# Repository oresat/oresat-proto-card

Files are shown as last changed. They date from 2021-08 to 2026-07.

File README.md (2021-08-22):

# "oresat-proto-card"

This is the "prototype" card for OreSat, meant to pioneer future cards and test the backplane, and be an 
easy way to hack in functionality. NOT MEANT FOR FLIGHT.

## Features

- Populates the two 1.27 mm connectors from the backplane.
- Populates all three SMPM RF connectors from the backplane.
- Standard TPS63070-bsaed buck/boost SPS (Vin = 2.5 to 7 V, Vout = 3.3V)
- Has our standard/favorite STM32F042K6 microcontroller.
   - With SWD, UART (FTDI), and CAN (to the backplane).
- Has lots of breakouts, but DO NOT POPULATE THE 0.1 IN CONNECTORS, THEY'RE TOO TALL!!!

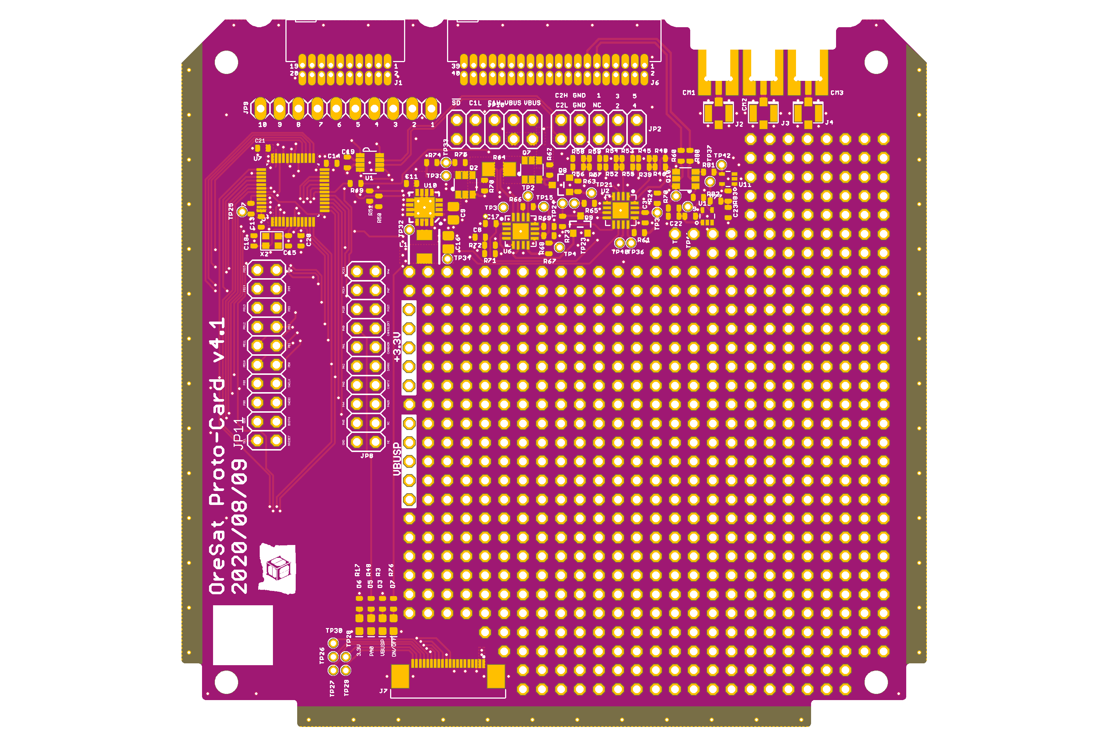
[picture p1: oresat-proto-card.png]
OreSat ProtoCard Picture


## Connector information

- Main 1.27 mm connector ("Center" connector)
   - Samtec TFM-120-01-L-D-RA
   - https://www.digikey.com/products/en?lang=en&site=US&keywords=TFM-120-01-L-D-RA
   - Drawing: http://suddendocs.samtec.com/prints/tfm-1xx-xx-xxx-d-xxx-mkt.pdf
   - Brochure: http://suddendocs.samtec.com/catalog_english/tfm.pdf
   - 3D CAD: https://www.samtec.com/partnumber/tfm-120-01-l-d-ra?vendor=digikey#technical
   - Notes: the -RE1 model is better because of the solder stakes, but the female connector doesn't fit! The stakes get in the way :(

- Auxiliary 1.27 mm ("alt-left" connector)
   - Samtec TFM-110-01-L-D-RA

- RF (70 cm, L band, S band) conenctors
   - Card
      - Molex 73300-0030 (possible replacement is 73300-0020 but it has full detent that we don't want)
      - SMPM Connector Plug, Male Pin 50 Ohm Board Edge, Cutout; Surface Mount Solder, smooth bore
      - Molex w/3D: https://www.molex.com/molex/products/datasheet.jsp?part=active/0733000030_RF_COAX_CONNECTORS.xml
   - Barrell (connects card to backplane)
      - Molex 73300-0220 (alt but slightly different lengths: -0223, -0228)
      - SMPM female to female barrel adapter 
      - RF Adapters - In Series SMPM JACK/JACK BULLET .21IN
      - Molex w/3D: https://www.molex.com/molex/products/datasheet.jsp?part=active/0733000220_RF_COAX_CONNECTORS.xml

## OreSat Power Domain (OPD)

You can find more design information on the OPD [here](https://docs.google.com/document/d/1NOkO6gGEJUFRpOrkwClRlZlzWuTLteq6fP9LPf_Ez0M/edit?usp=sharing).

## LICENSE

Copyright Portland State Aerospace Society 2018.

This documentation describes Open Hardware and is licensed under the CERN OHL v. 1.2.

You may redistribute and modify this documentation under the terms of the CERN OHL v.1.2. [http://ohwr.org/cernohl](http://ohwr.org/cernohl). This documentation is distributed WITHOUT ANY EXPRESS OR IMPLIED WARRANTY, INCLUDING OF MERCHANTABILITY, SATISFACTORY QUALITY AND FITNESS FOR A PARTICULAR PURPOSE. Please see the CERN OHL v.1.2 for applicable conditions.

## Version Information

Version | Date       | Notes
--------|------------|-------------------------
3.0     | 2018/11/22 | Big changes in structure, mostly springs. Changed RF connectors to SMPM. Optimized layout for more proto area. 
2.0     | 2018/03/?? | New 1.27 mm connectors, again.
1.0     | ??         | New connectors.

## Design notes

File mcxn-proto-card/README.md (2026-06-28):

---
title: "**OreSat MCXN Proto Card**"
subtitle: |
  **Fabrication and Assembly Information**\
  For build TIME-STAMP
fontsize: 10pt
geometry:
  - margin=0.5in
toc: true
toc-depth: 2
colorlinks: true
urlcolor: blue
---

\newpage

# About this Board

## Board Description

The OreSat MCXN Proto Card is a generic OreSat card based on the NXP MCXN947 microcontroller. It has an OreSat Power Domain (OPD), 
a CAN interface, an OreSat Card Debug port, a bzillion test points, and a 0.1 inch hole prototyping area.

The proto card also has the OreSat auxiliary connector and 3 RF backplane connectors, but these are not placed since they're not usually used.

## Documentation Links

- Git repository: <https://github.com/oresat/oresat-flatsat>
- **TODO:** Design Notes + Design Review Notes

## Documentation Files

| Filename | Notes |
| --- | --- |
| README.pdf | This README file |
| PROJECT-NAME-outline.dxf | Board outline (with holes) in DXF format |
| PROJECT-NAME-pcba.step | 3D model of PCBA (with components) |
| PROJECT-NAME-render-bot.jpg | Render of the top of the 3D model |
| PROJECT-NAME-render-bot.jpg | Render of the bottom of the 3D model |
| PROJECT-NAME-schematic.pdf | PDF of board schematics |

## Contact Information

- Website: <https://www.oresat.org/>
- Email: <oresat@pdx.edu>
- Instagram: @pdxaerospace

## Board Renders

Render of the top of the 3D model
Render of the bottom of the 3D model

\newpage

# Printed Circuit Board (PCB) Fabrication Information

## Board Info

- 4 layer board
- Bounding box is 99.8 x 94.6 mm
- Board thickness is 1.59 mm

## Board Requirements

- Design Rules
    - Minimum Trace / Space design rules
       - Outer layers: 0.127 mm (5.0 mil) / 0.127 mm (5.0 mil)
       - Inner layers: 0.127 mm (5.0 mil) / 0.127 mm (5.0 mil)
    - Outer dimension router tolerance: +/- 0.254 mm (10.0 mil)
    - Hole placement tolerance: +/- 0.075 mm (3.0 mil)
    - Inner tab routed slot tolerance: +/- 0.254 mm (10.0 mil)
- Drills
   - Drill Positional Tolerance: 0.051 mm (2.0 mil)
   - Drill Size tolerance: +/- 0.064 mm (2.5 mil)
- Plated/Un-plated holes
  - Via/PTH minimum diameter: 0.254 mm (10 mil)
  - Via/PTH minimum annulus: 0.102 mm (4 mil) radius
- Outline/Routing
  - This board requires a 1 mm router bit.
- Slots
  - There are no slots.
- Cutouts
  - There are no cutouts
- There are 3 fiducials on the top layer.
- Panel tabs ("mouse bites")
   - Card edges must be smooth; no mouse bites or other intrusions into the card outline.
   - If external mouse bites are required, minimize and customer will remove by hand before assembly.
- If not otherwise specified, build to IPC 6012 Class 2 or better.

## Stackup /  Materials

- Outside copper layers is 1 oz Cu after plating (0.043 mm / 1.7 mil)
- Inside copper layers are 0.5 oz Cu (0.018 mm / 0.7 mil)
- There are no requirements on the prepreg or core of this four layer stackup.
- Board Surface treatment should be ENIG, althogh immersion Silver is acceptable.
- White silkscreen on top and bottom surface
- Taiyo PSR-4000 or equivalent soldermask on top and bottom, no requirements for color.

## Array / Panel Information

- Coordinate with Contract Manufacturer (CM) for optimal size of this panel.
- If no feedback from CM, then produce single boards (no panel).

## Fabrication Files

### IPC-2581 File

| Filename | Notes |
| --- | --- |
| PROJECT-NAME-ipc2581.xml | IPC-2581 board information file |

### Legacy PCB Files

| Filename | Notes |
| ---| --- |
| PROJECT-NAME-Edge_Cuts.gbr | RS274X file for the dimension (outline) layer |
| PROJECT-NAME-F_Silkscreen.gbr | RS274X file for the top silkscreen |
| PROJECT-NAME-F_Mask.gbr | RS274X file for the top soldermask |
| PROJECT-NAME-F_Cu.gbr | RS274X file for the top copper layer |
| PROJECT-NAME-In1_Cu.gbr | RS274X file for the layer 2 copper |
| PROJECT-NAME-In2_Cu.gbr | RS274X file for the layer 3 copper |
| PROJECT-NAME-B_Cu.gbr | RS274X file for the bottom copper layer |
| PROJECT-NAME-B_Mask.gbr | RS274X file for the bottom soldermask |
| PROJECT-NAME-B_Silkscreen.gbr | RS274X file for the bottom silkscreen |
| PROJECT-NAME-NPTH.drl | Excellon file for non-plated through holes |
| PROJECT-NAME-PTH.drl | Excellon file for plated through holes | 

\newpage

# Printed Circuit Board Assembly (PCBA) Information

## Assembly Info

- All components are on the top side of the board.
- This PCBA uses both surface mount (SMT) and through-hole (THT) components.

## Assembly Requirements

- Assemble to IPC Class 2 or better
- Bake components that are not moisture sealed to appropriate levels as required.
- Any solder paste (leaded or RoHS) is acceptable. RoHS solder is slightly preferred.
- Any no-clean or aqueous wash flux is acceptable.
- No conformal coating.

## Component Specific Assembly Information

- No specific information

## Assembly Files

### IPC-2581 File

| Filename | Notes |
| --- | --- |
| PROJECT-NAME-ipc2581.xml | IPC-2581 board information file |

### Bill of Materials (BOM)

| Filename | Description |
| --- | --- |
| PROJECT-NAME-bom.csv | BOM in Comma Separated Variable format |

### Solder Paste Stencils

| Filename | Notes |
| --- | --- |
| PROJECT-NAME-B_Paste.gbr | RS274X file for top/front solder paste stencil |
| PROJECT-NAME-F_Paste.gbr | RS274X file for bottom/back solder paste stencil |

### Mounting/Placement Location

| Filename | Description |
| --- | --- |
| PROJECT-NAME.pos | Pick and place locations for components |

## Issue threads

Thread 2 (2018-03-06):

Getting feedback on the v1.1 prototype card

andrewgreenberg, 2018-03-06:
Rough draft of the v2 card is done! We're now awaiting feedback that we're not complete idiots on the v1.1. We need to know:

1. Does it power up?
1. Can you program the STM?
1. Can you blink the LED?
1. Can you talk over UART?
1. Can you talk over CAN?

At that point, we can fire on v2!

heliochronix, 2018-03-09:
Feedback so far:
CAN_EN (PA10) and CAN_LSTN (PA9) are mislabeled, similar to the Solar V1 issue. They are connected to SHDN (Shutdown mode) and S (Silent mode) on the TCAN330.  Maybe rename CAN_SHDN and CAN_SILENT?

1. Powers up: Check
2. Programmable: Check
3. LED Blinks: Working on it. Some kinda hitch right now.
4. UART: Need to test
5. CAN: Need to test

andrewgreenberg, 2018-03-09:
Fixed in future OreSat Proto Card and on solar v2 boards. Now called CAN_SHDN and CAN_SILENT, as suggested. Go Miles go!

heliochronix, 2018-03-09:
1. Does it power up? Yes!
2. Can you program the STM? Yes!
3. Can you blink the LED? Yes!
4. Can you talk over UART? Yes!
5. Can you talk over CAN? Yes!

Closed 2018-03-09.

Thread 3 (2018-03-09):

FTDI Header has TX/RX swapped

heliochronix, 2018-03-09:
USART2_RX should connect to pin 4 (RXI)
USART2_TX should connect to pin 5 (TXO).

andrewgreenberg, 2018-03-12:
Fixed!

Closed 2018-03-12.

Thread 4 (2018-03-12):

Request power via FTDI Vcc

heliochronix, 2018-03-12:
Request a jumper or something be added to allow an FTDI cable's Vcc to supply power to the board. This will ease the requirement of needing an additional power supply when developing.

andrewgreenberg, 2018-03-12:
Added 1x2 0.1" jumper to go from FTDI VCC to VBUS.

Closed 2018-03-12.

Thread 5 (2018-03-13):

Power LED labelled VBAT instead of VBUS

heliochronix, 2018-03-13:
Simple as that. The LED for power is labelled VBAT and I noticed everything else is labelled VBUS now.

andrewgreenberg, 2018-03-13:
Fixed and pushed!

Closed 2018-03-13.

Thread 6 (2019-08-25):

OPD breaker trips with inrush current.

davidalay, 2019-08-25:
the OPD breaker trips from the inrush current when the board is powered on.  Can be reset, stuffing the reset circuitry should fix the problem

Closed 2020-06-22.

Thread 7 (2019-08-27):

IO0 on MAX7310 is open drain

davidalay, 2019-08-27:
IO0 on the IO expander is only open drain, needs to be switched with one of the other pins that can work with open drain (I2C?).   Cutting the trace and soldering a jumper from tp13 to tp10 to tie to the indicator LED should work as a temp fix.

Closed 2019-09-11.

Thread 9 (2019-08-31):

10-pin JTAG header is flipped/mirrored

heliochronix, 2019-08-31:
The JTAG header on these boards is opposite of what it should be. That is, 3.3V is on the "top left" in Eagle but it should be the "top right" and likewise for the "bottom left" and "bottom right". All the pins are mirrored "left-to-right".

davidalay, 2019-12-07:
Part fixed in the oresat eagle libraries

Closed 2019-12-07.

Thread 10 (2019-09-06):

I2C protection

davidalay, 2019-09-06:
Weird gate capacitance stuff happens with the I2C protection circuit.  New design coming in future revs to fix issue.  For now DNP the I2C MOSFETS and short the lines together.

davidalay, 2019-11-05:
Fixed in most recent push

davidalay, 2019-11-05:
Fixed in most recent push

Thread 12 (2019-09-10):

MAX4211 dies if VBUSP is shorted

davidalay, 2019-09-10:
The MAX4211 circuit breaker dies if VBUSP is shorted.  We are pretty sure its because the MCP1703 is dying.  Perhaps a diode and cap to fix?

Closed 2020-06-22.

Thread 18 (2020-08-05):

Oresat Debug Connector: Add TCREAM back on ground pads of thin debug connector

andrewgreenberg, 2020-08-05:

andrewgreenberg, 2020-08-09:
Won't fix; abandoning this connector because it's complete garbage.

Closed 2020-08-09.

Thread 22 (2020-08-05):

Remove STM32F04 from BOM and replace with STM32F09

davidalay, 2020-08-05:

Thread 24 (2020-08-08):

Protocard: Ciss (input capacitance) from P CH in OPD protection circuitry kills I2C rise times

andrewgreenberg, 2020-08-08:
The 300 pF input capacitance of the DMP2240UDM-7 dual P channel MOSFET (Q10)  we use in the I2C protection circuit (before the MAX7310) was killing the I2C signal. Removing the MIC comparitor, and just having the 10K to ground on the Q10 gates was too much. Raising that resistor to > 100k seems to solve the problem "enough".

So: change R77 and R81 to 665K (we already have that value) and move them between the MIC output and transistor. We'll have to no longer have the gate be pulled low, which seems OK? If we really want one, a 1 M to ground is probably OK but it'll affect the gate drive of the MIC so that'll have to be explored.

andrewgreenberg, 2020-08-09:
Fixed in DBLs; still needs to fix in protocard.

andrewgreenberg, 2020-08-10:
Fixed in protocard, now just need to hack existing v4.0 protoboards into compliance

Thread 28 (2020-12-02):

Implement inhibit RC filter on MAX4311 CB IC

andrewgreenberg, 2020-12-02:
See design.md in the protocard repo: C = 1 uF (Vw >= 16V), R = 100k, and then a 10k into the MAX4311 to protect it.

andrewgreenberg, 2020-12-02:
This is for DBL, protocard, and everything with an OPD.

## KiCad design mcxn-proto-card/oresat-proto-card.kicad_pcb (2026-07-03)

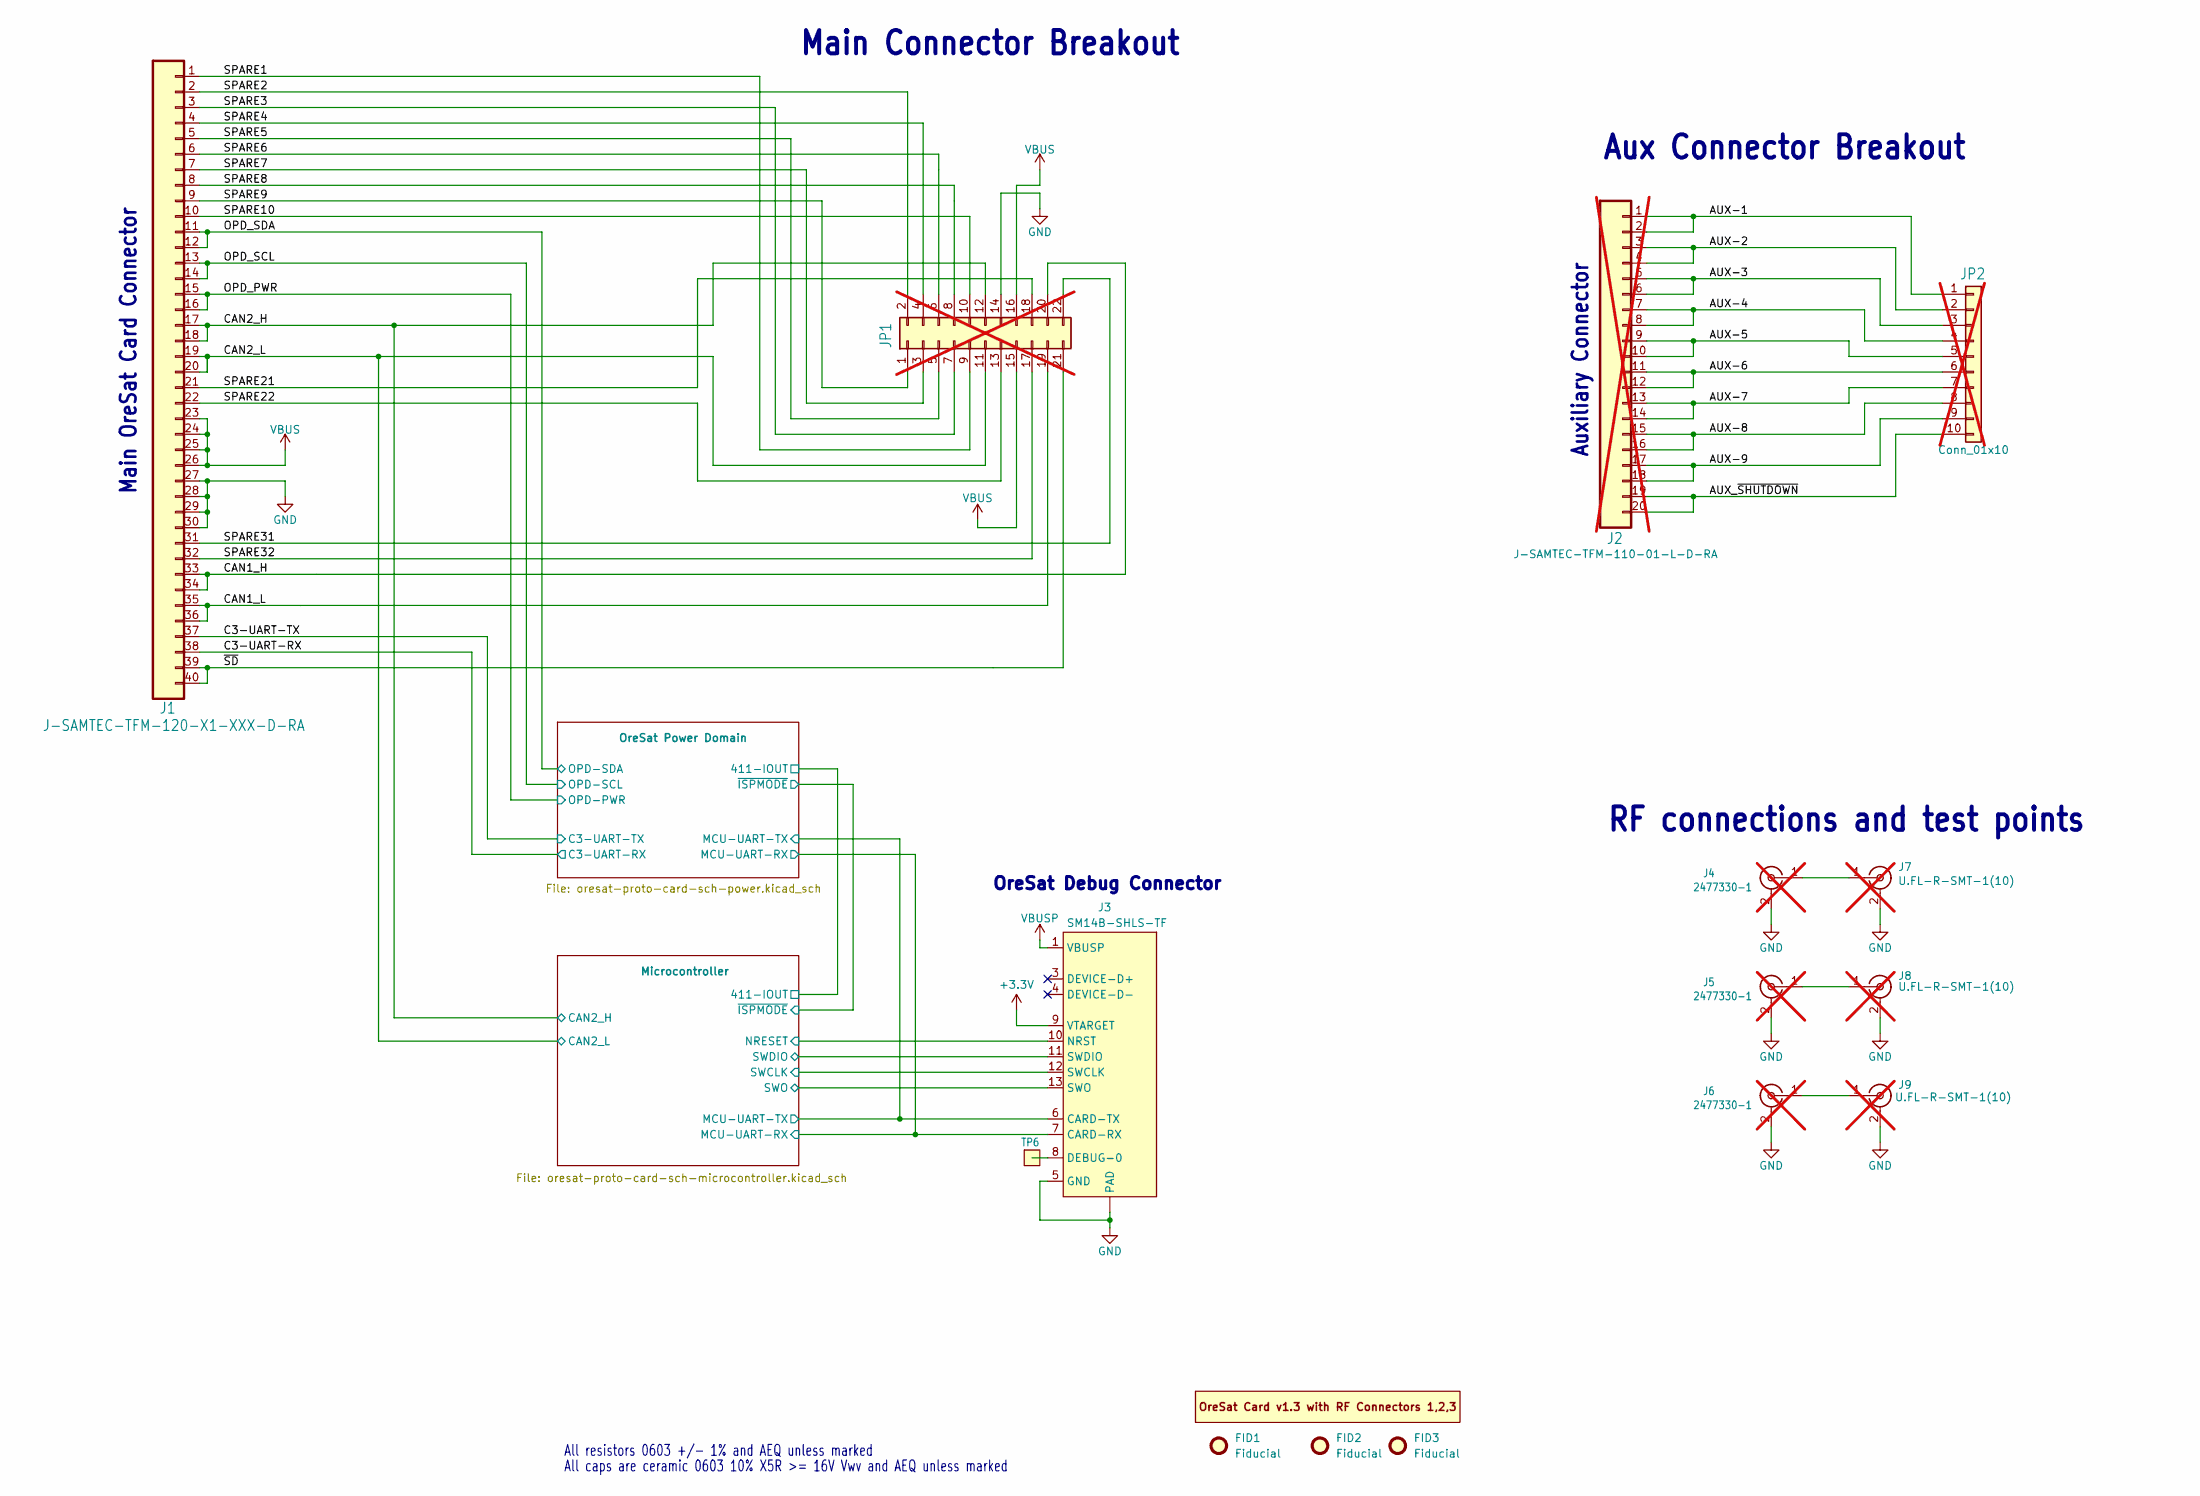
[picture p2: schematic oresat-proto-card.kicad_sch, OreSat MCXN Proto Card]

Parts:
FID1, FID2, FID3: Fiducial; Fiducial_1mm_Mask2mm
J1: J-SAMTEC-TFM-120-X1-XXX-D-RA; MPN TFM-120-01-L-D-RA
J2: J-SAMTEC-TFM-110-01-L-D-RA; J-SAMTEC-TFM-110-X1-XXX-D-RA; MPN TFM-110-01-L-D-RA; not fitted
J3: SM14B-SHLS-TF; J-JST-SM14BSHLSTF; MPN SM14B-SHLS-TF
J4, J5, J6: 2477330-1; J-MOLEX-SMPM-073300-002X; MPN 2477330-1; not fitted
J7, J8, J9: U.FL-R-SMT-1(10); U.FL_Hirose_U.FL-R-SMT-1_Vertical; MPN U.FL-R-SMT-1(10); not fitted
JP1: PINHD-2X5; PinHeader_2x11_P2.54mm_Vertical; not fitted
JP2: Conn_01x10; PinHeader_1x10_P2.54mm_Vertical; MPN 61302011121; not fitted
PCB1: ORESAT-CARD-V1.3-3RF; MPN oresat-proto-card-v6.0-2025-12-28
TP6: Test-Point; TestPoint-0.75mm-th

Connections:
+3.3V: J3.9 (VTARGET); also elsewhere on the board
/AUX-1: J2.1, J2.2, JP2.1
/AUX-2: J2.3, J2.4, JP2.2
/AUX-3: J2.5, J2.6, JP2.3
/AUX-4: J2.7, J2.8, JP2.4
/AUX-5: J2.9, J2.10, JP2.5
/AUX-6: J2.11, J2.12, JP2.6
/AUX-7: J2.13, J2.14, JP2.7
/AUX-8: J2.15, J2.16, JP2.8
/AUX-9: J2.17, J2.18, JP2.9
/AUX_~SHUTDOWN: J2.19, J2.20, JP2.10
/C3-UART-RX: J1.38; also elsewhere on the board
/C3-UART-TX: J1.37; also elsewhere on the board
/CAN1_H: J1.33, J1.34, JP1.20
/CAN1_L: J1.35, J1.36, JP1.19
/CAN2_H: J1.17, J1.18, JP1.12; also elsewhere on the board
/CAN2_L: J1.19, J1.20, JP1.11; also elsewhere on the board
/Microcontroller/MCU-UART-RX: J3.7 (CARD-RX); also elsewhere on the board
/Microcontroller/MCU-UART-TX: J3.6 (CARD-TX); also elsewhere on the board
/Microcontroller/NRESET: J3.10 (NRST); also elsewhere on the board
/Microcontroller/SWCLK: J3.12 (SWCLK); also elsewhere on the board
/Microcontroller/SWDIO: J3.11 (SWDIO); also elsewhere on the board
/Microcontroller/SWO: J3.13 (SWO); also elsewhere on the board
/OPD_PWR: J1.15, J1.16; also elsewhere on the board
/OPD_SCL: J1.13, J1.14; also elsewhere on the board
/OPD_SDA: J1.11, J1.12; also elsewhere on the board
/SPARE1: J1.1, JP1.9
/SPARE2: J1.2, JP1.2
/SPARE3: J1.3, JP1.7
/SPARE4: J1.4, JP1.4
/SPARE5: J1.5, JP1.5
/SPARE6: J1.6, JP1.6
/SPARE7: J1.7, JP1.3
/SPARE8: J1.8, JP1.8
/SPARE9: J1.9, JP1.1
/SPARE10: J1.10, JP1.10
/SPARE21: J1.21, JP1.18
/SPARE22: J1.22, JP1.13
/SPARE31: J1.31, JP1.22
/SPARE32: J1.32, JP1.17
/~SD: J1.39, J1.40, JP1.21
GND: J1.27, J1.28, J1.29, J1.30, J3.5 (GND), J3.14 (GND), J3.15 (PAD), J3.16 (PAD), J4.2 (Ext), J5.2 (Ext), J6.2 (Ext), J7.2 (Ext), J8.2 (Ext), J9.2 (Ext), JP1.14; also elsewhere on the board
unnamed: J3.8 (DEBUG-0), TP6.1 (1_1)
unnamed: J4.1 (In), J7.1 (In)
unnamed: J5.1 (In), J8.1 (In)
unnamed: J6.1 (In), J9.1 (In)
VBUS: J1.23, J1.24, J1.25, J1.26, JP1.15, JP1.16; also elsewhere on the board
VBUSP: J3.1 (VBUSP), J3.2 (VBUSP); also elsewhere on the board

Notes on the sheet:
All caps are ceramic 0603 10% X5R >= 16V Vwv and AEQ unless marked
All resistors 0603 +/- 1% and AEQ unless marked
RF connections and test points
Main Connector Breakout
OreSat Debug Connector
Main OreSat Card Connector
Aux Connector Breakout
Auxiliary Connector

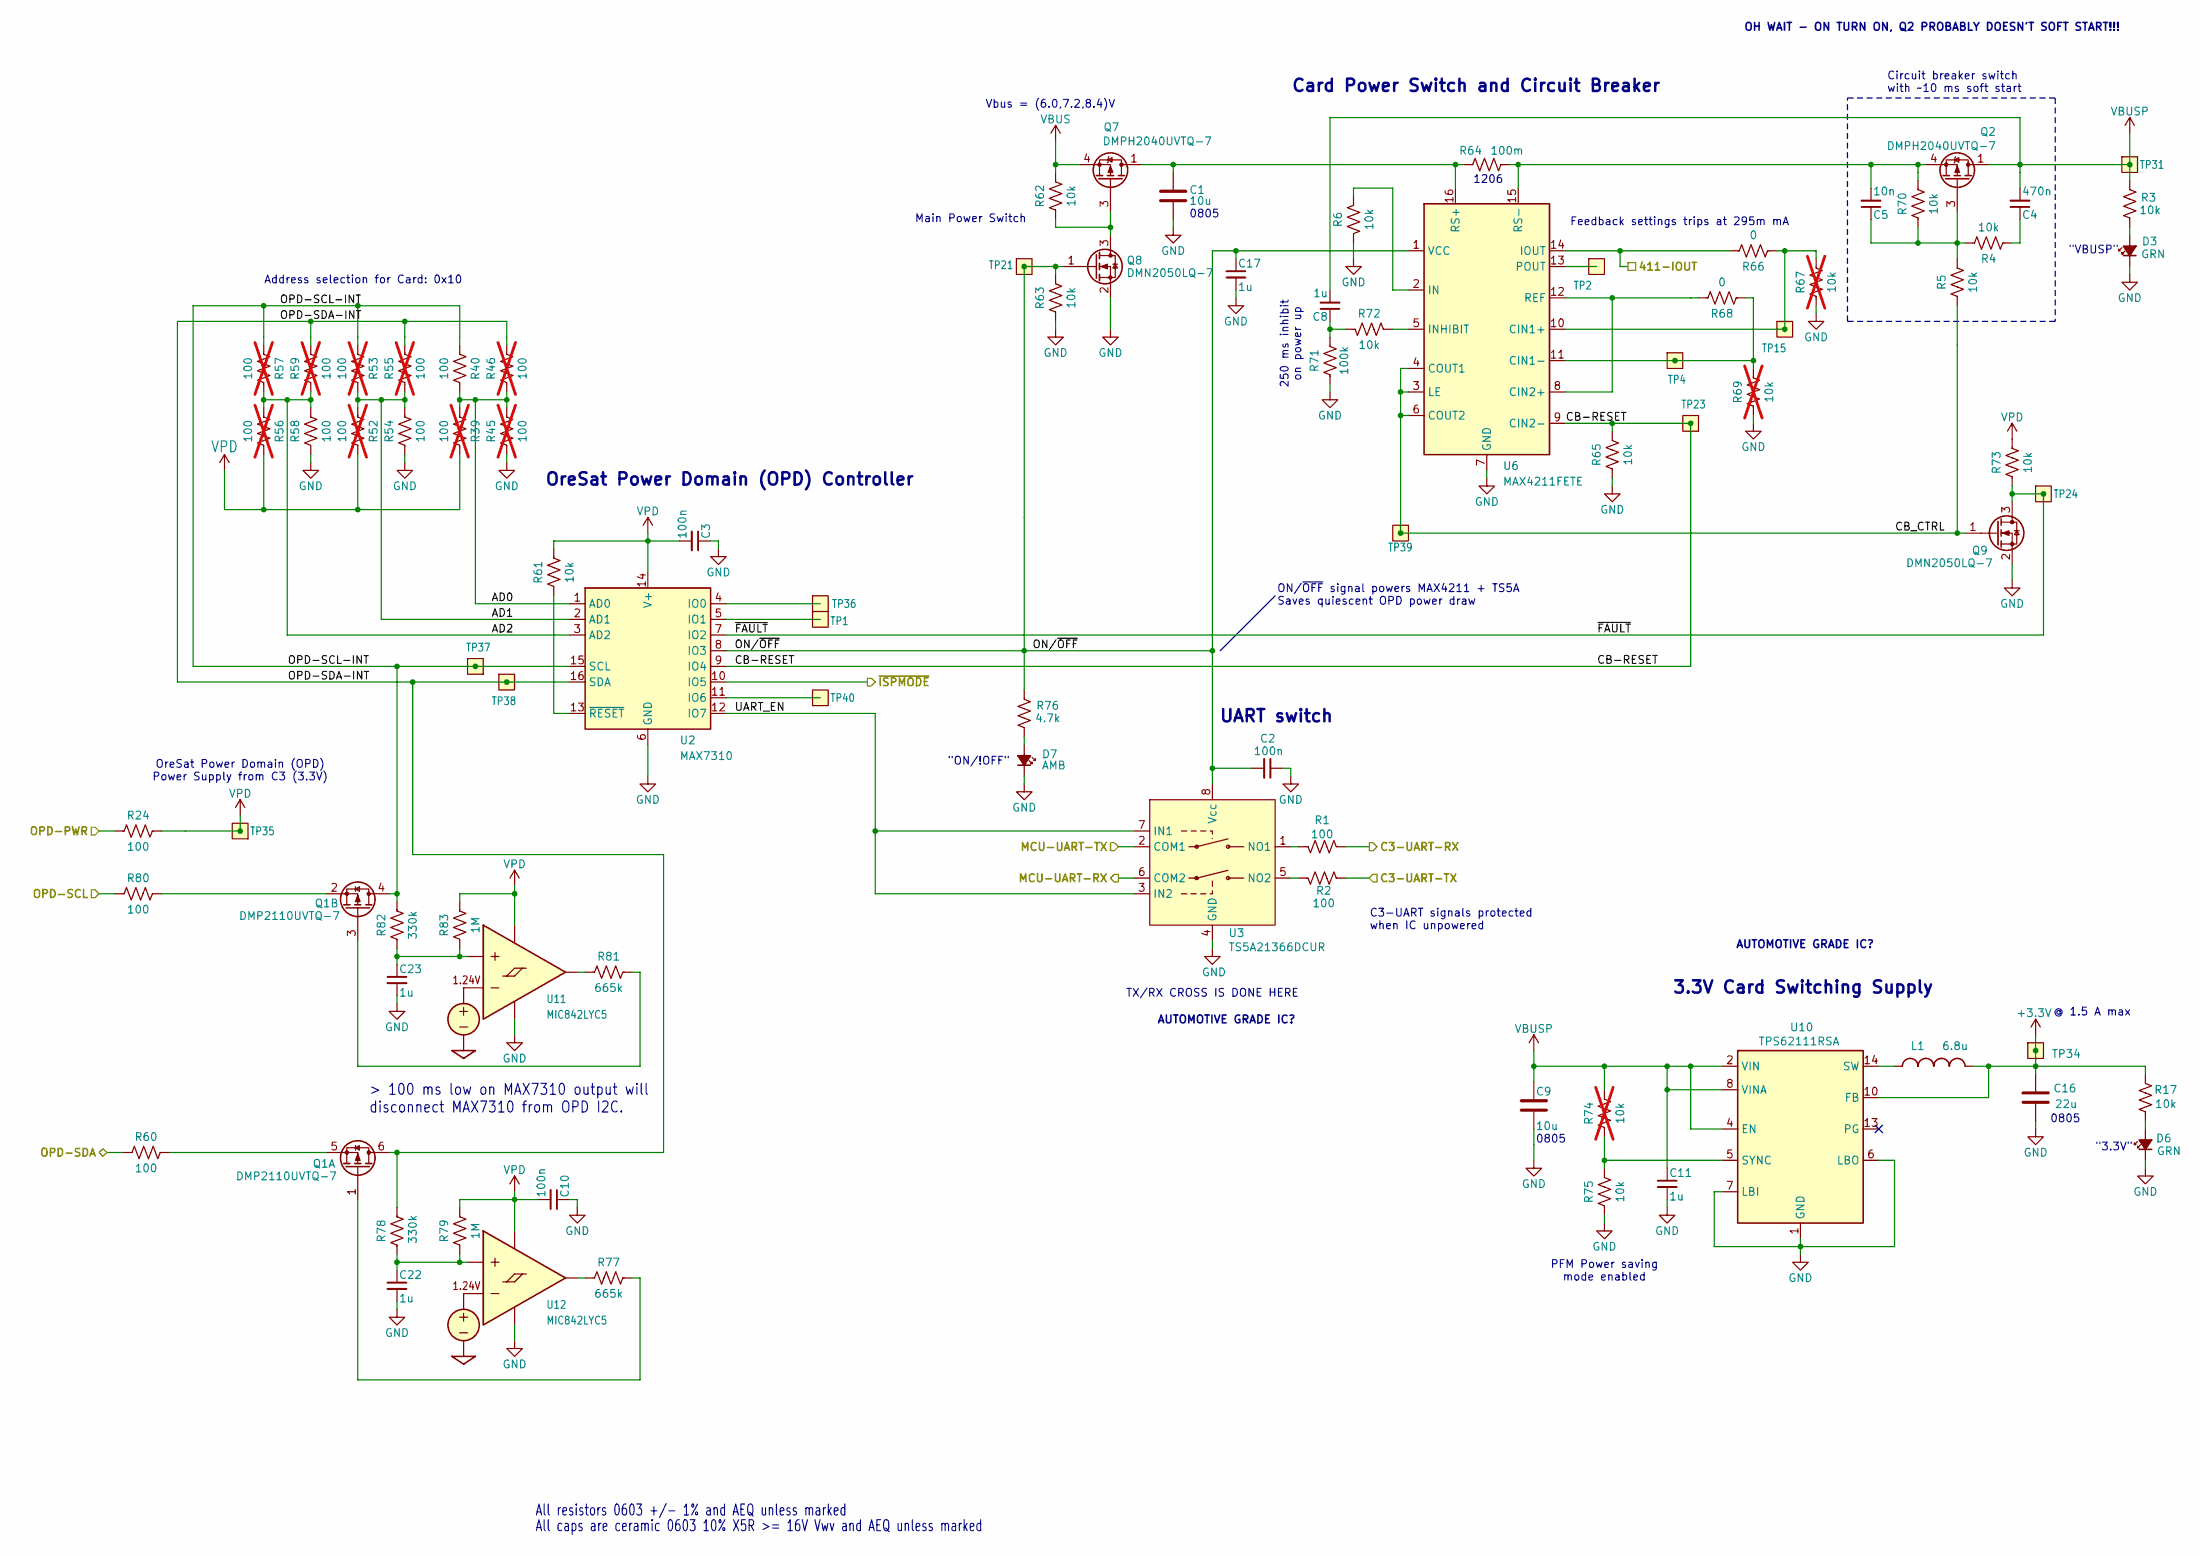
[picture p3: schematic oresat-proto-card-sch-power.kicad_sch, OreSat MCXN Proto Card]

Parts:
C1, C9: 10u; 0805-B-NOSILK; MPN GRT21BC71E106KE13K
C2, C3, C10: 100n; 0603-C-NOSILK; MPN C0603C104K5RACAUTO
C4: 470n; 0603-C-NOSILK; MPN C0603C474K3RACAUTO
C5: 10n; 0603-C-NOSILK; MPN C0603C103K5RACAUTO
C8, C11, C17, C22, C23: 1u; 0603-C-NOSILK; MPN GRT188R71E105KE13D
C16: 22u; 0805-C-NOSILK; MPN GRT21BC81C226ME13L
D3, D6: GRN; LED_0603_1608Metric; MPN 150060GS75000
D7: AMB; LED_0603_1608Metric; MPN 150060AS75000
L1: 6.8u; L_ECS-MPI4040; MPN ECS-MPI4040R4-6R8-R
Q1: DMP2110UVTQ-7; SOT-23-6; MPN DMP2110UVTQ-7
Q2, Q7: DMPH2040UVTQ-7; TSOT-23-6; MPN DMPH2040UVTQ-7
Q8, Q9: DMN2050LQ-7; SOT-23; MPN DMN2050LQ-7
R1, R2, R24, R40, R54, R58, R60, R80: 100; 0603-C-NOSILK; MPN RMCF0603FT100R
R3, R4, R5, R6, R17, R61, R62, R63, R65, R70, R72, R73, R75: 10k; 0603-C-NOSILK; MPN RMCF0603FT10K0
R39, R45, R46, R52, R53, R55, R56, R57, R59: 100; 0603-C-NOSILK; MPN RMCF0603FT100R; not fitted
R64: 100m; R_1206_3216Metric; MPN CSR1206FKR100
R66, R68: 0; 0603-C-NOSILK; MPN RMCF0603ZT0R00
R67, R69, R74: 10k; 0603-C-NOSILK; MPN RMCF0603FT10K0; not fitted
R71: 100k; 0603-C-NOSILK; MPN RMCF0603FT100K
R76: 4.7k; 0603-C-NOSILK; MPN RMCF0603FT4K70
R77, R81: 665k; 0603-C-NOSILK; MPN RMCF0603FT665K
R78, R82: 330k; 0603-C-NOSILK; MPN RMCF0603FT330K
R79, R83: 1M; 0603-C-NOSILK; MPN RMCF0603FT1M00
TP1, TP2, TP4, TP15, TP21, TP23, TP24, TP31, TP34, TP35, TP36, TP37, TP38, TP39, TP40: Test-Point; TestPoint-0.75mm-th
U2: MAX7310; QFN-16-1EP_4x4mm_P0.65mm_EP2.1x2.1mm; MPN MAX7310ATE
U3: TS5A21366DCUR; VSSOP-8_2.3x2mm_P0.5mm; MPN TS5A21366DCUR
U6: MAX4211FETE; QFN-16-1EP_4x4mm_P0.65mm_EP2.1x2.1mm; MPN MAX4211FETE
U10: TPS62111RSA; Texas_RSA_VQFN-16-1EP_4x4mm_P0.65mm_EP2.7x2.7mm; MPN TPS62111RSA
U11, U12: MIC842LYC5; SOT-353_SC-70-5; MPN MIC842LYC5-TR

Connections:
+3.3V: C16.1, L1.2, R17.2, TP34.1 (1_1), U10.10 (FB); also elsewhere on the board
/C3-UART-RX: R1.1; also elsewhere on the board
/C3-UART-TX: R2.1; also elsewhere on the board
/Microcontroller/411-IOUT: R66.2, U6.14 (IOUT); also elsewhere on the board
/Microcontroller/MCU-UART-RX: U3.6 (COM2); also elsewhere on the board
/Microcontroller/MCU-UART-TX: U3.2 (COM1); also elsewhere on the board
/Microcontroller/~ISPMODE: U2.10 (IO5); also elsewhere on the board
/OPD_PWR: R24.1; also elsewhere on the board
/OPD_SCL: R80.1; also elsewhere on the board
/OPD_SDA: R60.1; also elsewhere on the board
/OreSat Power Domain/AD0: R39.1, R40.2, R45.2, R46.1, U2.1 (AD0)
/OreSat Power Domain/AD1: R52.1, R53.2, R54.2, R55.1, U2.2 (AD1)
/OreSat Power Domain/AD2: R56.1, R57.2, R58.2, R59.1, U2.3 (AD2)
/OreSat Power Domain/CB-RESET: R65.2, TP23.1 (1_1), U2.9 (IO4), U6.9 (CIN2-)
/OreSat Power Domain/CB_CTRL: Q9.1 (G), R5.1, TP39.1 (1_1), U6.3 (LE), U6.4 (COUT1), U6.6 (COUT2)
/OreSat Power Domain/ON/~OFF: C2.2, C17.1, Q8.1 (G), R63.2, R76.1, TP21.1 (1_1), U2.8 (IO3), U3.8 (Vcc), U6.1 (VCC)
/OreSat Power Domain/OPD-SCL-INT: Q1.4 (D), R40.1, R53.1, R57.1, R82.2, TP37.1 (1_1), U2.15 (SCL)
/OreSat Power Domain/OPD-SDA-INT: Q1.6 (D), R46.2, R55.2, R59.2, R78.2, TP38.1 (1_1), U2.16 (SDA)
/OreSat Power Domain/UART_EN: U2.12 (IO7), U3.3 (IN2), U3.7 (IN1)
/OreSat Power Domain/~FAULT: Q9.3 (D), R73.1, TP24.1 (1_1), U2.7 (IO2)
GND: C1.2, C2.1, C3.1, C9.2, C10.1, C11.2, C16.2, C17.2, C22.2, C23.2, D3.1 (K), D6.1 (K), D7.1 (K), Q8.2 (S), Q9.2 (S), R6.2, R45.1, R54.1, R58.1, R63.1, R65.1, R67.1, R69.1, R71.1, R75.1, U2.6 (GND), U2.17 (GND), U3.4 (GND), U6.7 (GND), U6.17 (GND), U10.1 (GND), U10.6 (LBO), U10.7 (LBI), U10.9 (GND), U10.11 (GND), U10.12 (GND), U10.16 (GND), U10.17 (GND), U11.2 (GND), U12.2 (GND); also elsewhere on the board
unnamed: C4.1, R4.1
unnamed: C8.1, R71.2, R72.2
unnamed: D3.2 (A), R3.1
unnamed: D6.2 (A), R17.1
unnamed: D7.2 (A), R76.2
unnamed: L1.1, U10.14 (SW), U10.15 (SW)
unnamed: Q1.1 (G), R77.2
unnamed: Q1.5 (S), R60.2
unnamed: Q1.3 (G), R81.2
unnamed: Q1.2 (S), R80.2
unnamed: C5.1, Q2.3 (G), R4.2, R5.2, R70.1
unnamed: C5.2, Q2.4 (S), R64.2, R70.2, U6.15 (RS-)
unnamed: Q7.3 (G), Q8.3 (D), R62.1
unnamed: TP36.1 (1_1), U2.4 (IO0)
unnamed: TP1.1 (1_1), U2.5 (IO1)
unnamed: TP40.1 (1_1), U2.11 (IO6)
unnamed: R61.1, U2.13 (~RESET)
unnamed: R1.2, U3.1 (NO1)
unnamed: R2.2, U3.5 (NO2)
unnamed: R66.1, R67.2, TP15.1 (1_1), U6.10 (CIN1+)
unnamed: R68.1, R69.2, TP4.1 (1_1), U6.11 (CIN1-)
unnamed: R68.2, U6.8 (CIN2+), U6.12 (REF)
unnamed: R6.1, U6.2 (IN)
unnamed: R72.1, U6.5 (INHIBIT)
unnamed: TP2.1 (1_1), U6.13 (POUT)
unnamed: C1.1, Q7.1 (D), Q7.2 (D), Q7.5 (D), Q7.6 (D), R64.1, U6.16 (RS+)
unnamed: R74.1, R75.2, U10.5 (SYNC)
unnamed: C23.1, R82.1, R83.1, U11.1 (INP)
unnamed: R81.1, U11.4 (OUT)
unnamed: C22.1, R78.1, R79.1, U12.1 (INP)
unnamed: R77.1, U12.4 (OUT)
VBUS: Q7.4 (S), R62.2; also elsewhere on the board
VBUSP: C4.2, C8.2, C9.1, C11.1, Q2.1 (D), Q2.2 (D), Q2.5 (D), Q2.6 (D), R3.2, R74.2, TP31.1 (1_1), U10.2 (VIN), U10.3 (VIN), U10.4 (EN), U10.8 (VINA); also elsewhere on the board
VPD: C3.2, C10.2, R24.2, R39.2, R52.2, R56.2, R61.2, R73.2, R79.2, R83.2, TP35.1 (1_1), U2.14 (V+), U11.5 (VDD), U12.5 (VDD)

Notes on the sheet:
ON/~{OFF} signal powers MAX4211 + TS5A Saves quiescent OPD power draw
Feedback settings trips at 295m mA
Card Power Switch and Circuit Breaker
1206
3.3V Card Switching Supply
"3.3V"
OH WAIT - ON TURN ON, Q2 PROBABLY DOESN'T SOFT START!!!
> 100 ms low on MAX7310 output will disconnect MAX7310 from OPD I2C.
C3-UART signals protected when IC unpowered
OreSat Power Domain (OPD) Power Supply from C3 (3.3V)
Vbus = (6.0,7.2,8.4)V
All resistors 0603 +/- 1% and AEQ unless marked
0805
OreSat Power Domain (OPD) Controller
"VBUSP"
All caps are ceramic 0603 10% X5R >= 16V Vwv and AEQ unless marked
250 ms inhibit on power up
@ 1.5 A max
PFM Power saving mode enabled
"ON/!OFF"
TX/RX CROSS IS DONE HERE
Address selection for Card: 0x10
Circuit breaker switch with ~10 ms soft start
AUTOMOTIVE GRADE IC?
Main Power Switch
UART switch

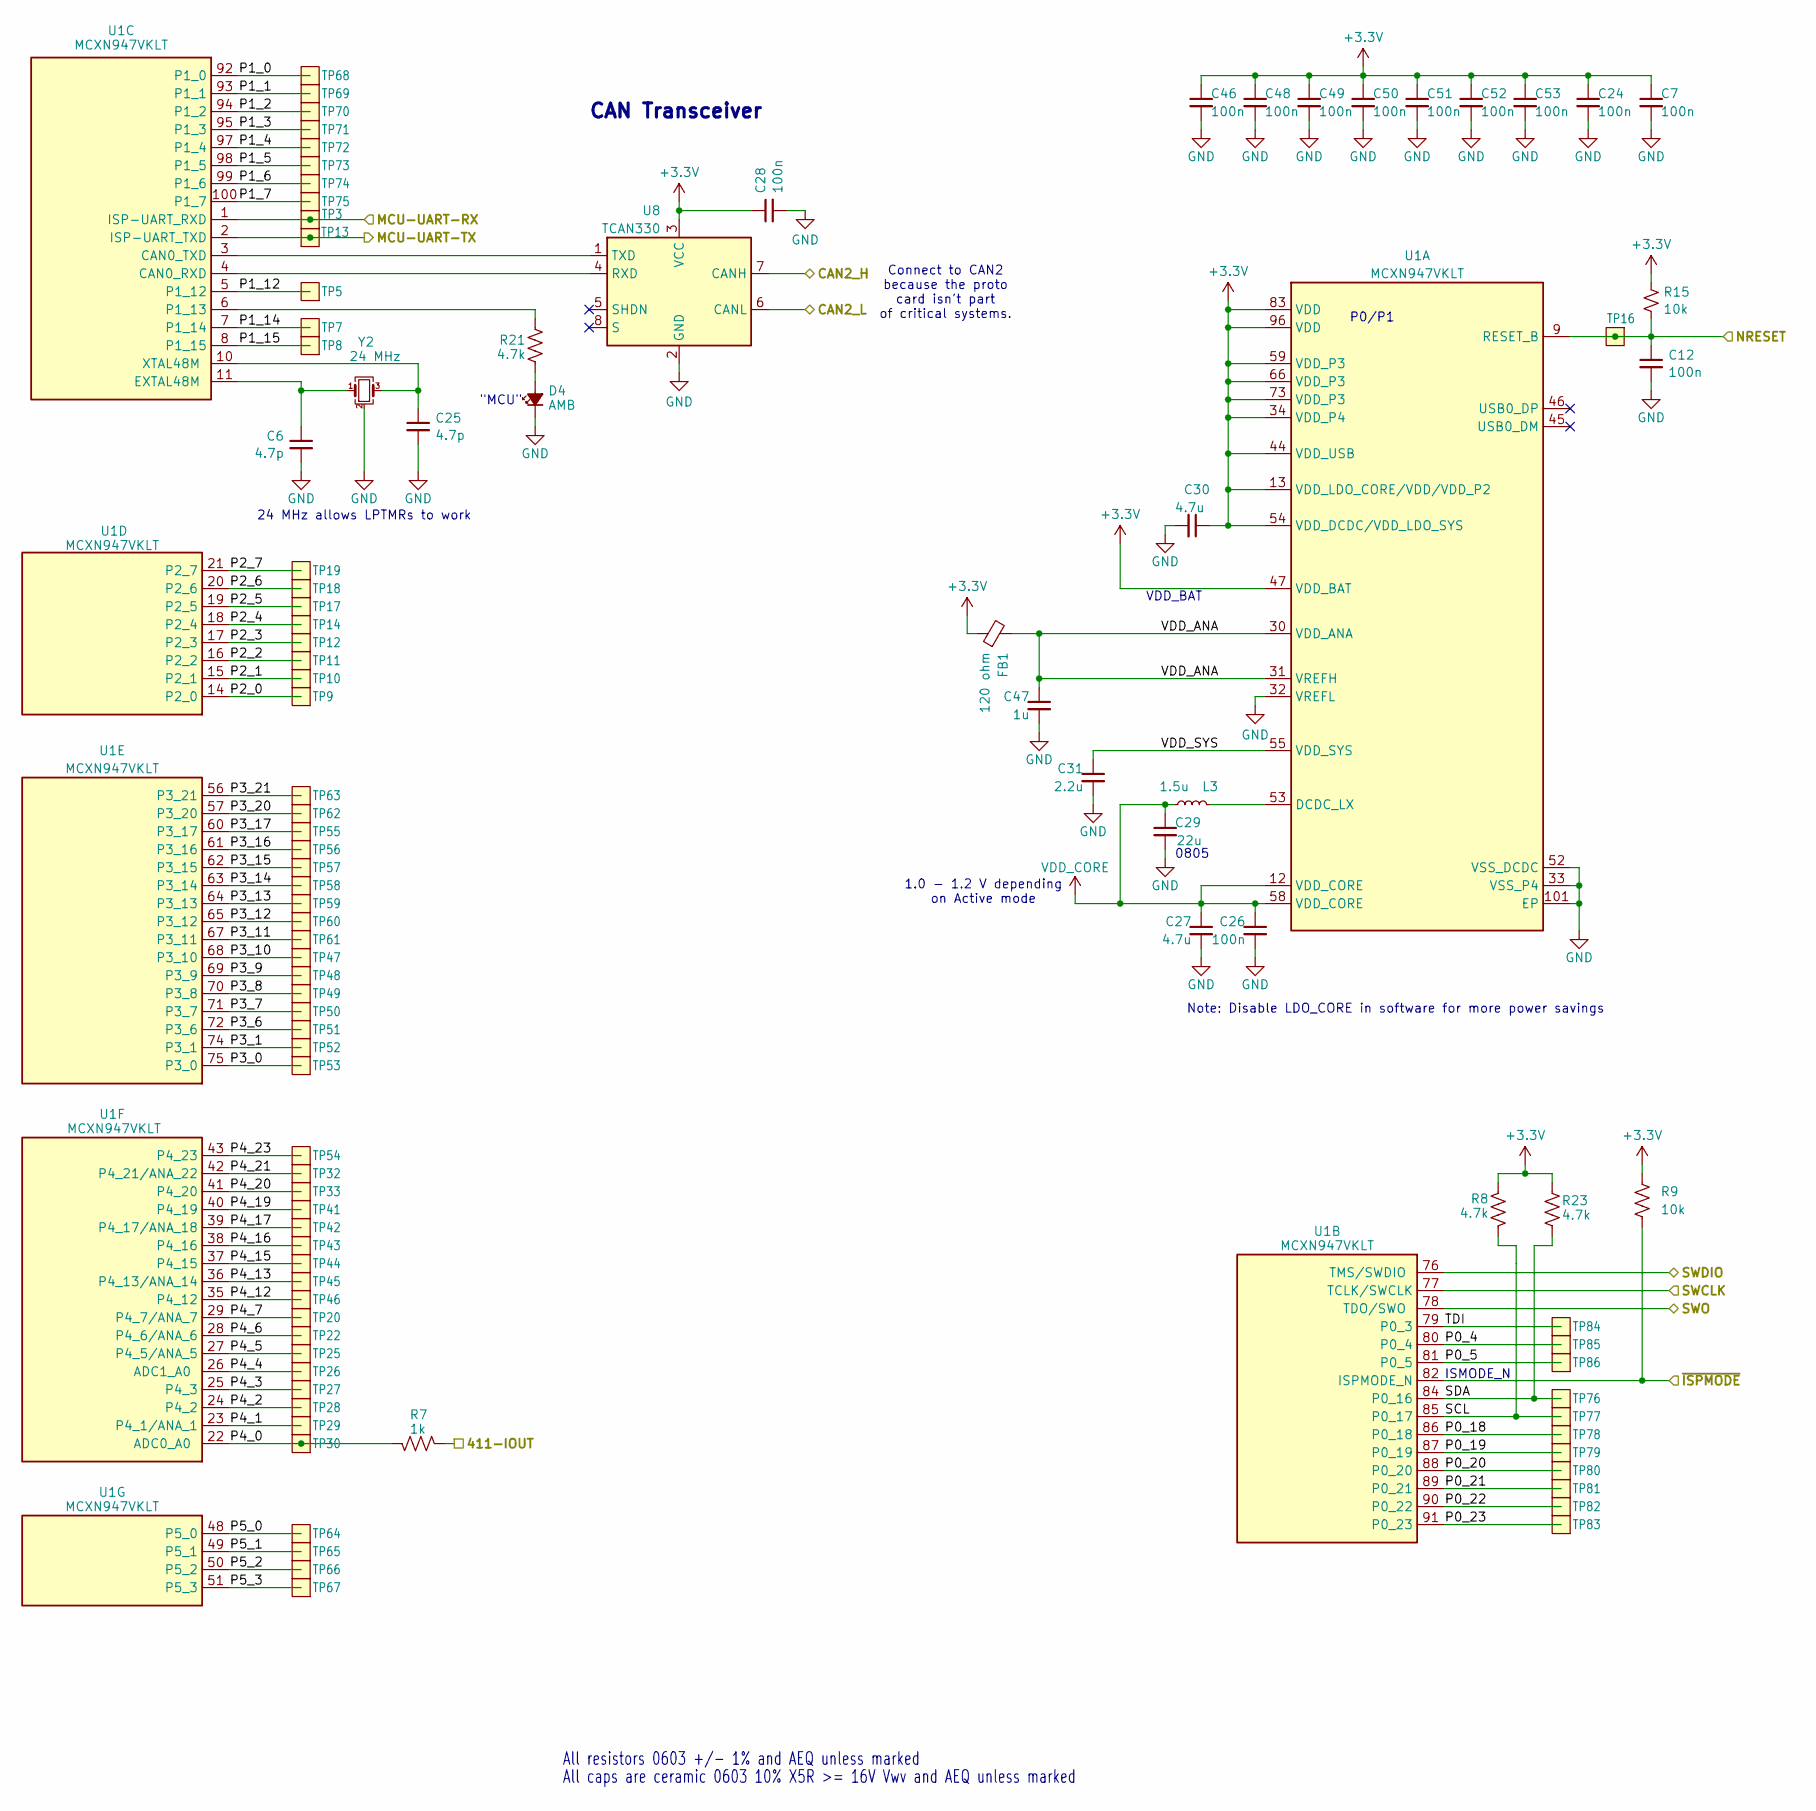
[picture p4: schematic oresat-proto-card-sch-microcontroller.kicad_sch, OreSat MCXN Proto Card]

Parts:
C6, C25: 4.7p; 0603-C-NOSILK; MPN C0603C479D5GACAUTO
C7, C12, C24, C26, C28, C46, C48, C49, C50, C51, C52, C53: 100n; 0603-C-NOSILK; MPN C0603C104K5RACAUTO
C27, C30: 4.7u; 0603-C-NOSILK; MPN EMK107BBJ475KAHT
C29: 22u; 0805-C-NOSILK; MPN GRT21BC81C226ME13L
C31: 2.2u; 0603-C-NOSILK; MPN GRT188C71E225KE13D
C47: 1u; 0603-C-NOSILK; MPN GRT188R71E105KE13D
D4: AMB; LED_0603_1608Metric; MPN 150060AS75000
FB1: 120 ohm; 0805-B-NOSILK; MPN 2508051217Y6
L3: 1.5u; L_0805_2012Metric; MPN SRP2012TMA-1R5M
R7: 1k; 0603-C-NOSILK; MPN RMCF0603FT1K00
R8, R21, R23: 4.7k; 0603-C-NOSILK; MPN RMCF0603FT4K70
R9, R15: 10k; 0603-C-NOSILK; MPN RMCF0603FT10K0
TP3, TP5, TP7, TP8, TP9, TP10, TP11, TP12, TP13, TP14, TP16, TP17, TP18, TP19, TP20, TP22, TP25, TP26, TP27, TP28, TP29, TP30, TP32, TP33, TP41, TP42, TP43, TP44, TP45, TP46, TP47, TP48, TP49, TP50, TP51, TP52, TP53, TP54, TP55, TP56, TP57, TP58, TP59, TP60, TP61, TP62, TP63, TP64, TP65, TP66, TP67, TP68, TP69, TP70, TP71, TP72, TP73, TP74, TP75, TP76, TP77, TP78, TP79, TP80, TP81, TP82, TP83, TP84, TP85, TP86: Test-Point; TestPoint-0.75mm-th
U1: MCXN947VKLT; MCXN947KVLT-QFP50P1600X1600X160-101N; MPN MCXN947VKLT
U8: TCAN330; SOT-23-8; MPN TCAN330DCNR
Y2: 24 MHz; Crystal_SMD_2016-4Pin_2.0x1.6mm; MPN 830108212309

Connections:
+3.3V: C7.1, C24.1, C28.1, C30.1, C46.1, C48.1, C49.1, C50.1, C51.1, C52.1, C53.1, FB1.1, R8.2, R9.2, R15.2, R23.2, U1.13 (VDD_LDO_CORE/VDD/VDD_P2), U1.34 (VDD_P4), U1.44 (VDD_USB), U1.47 (VDD_BAT), U1.54 (VDD_DCDC/VDD_LDO_SYS), U1.59 (VDD_P3), U1.66 (VDD_P3), U1.73 (VDD_P3), U1.83 (VDD), U1.96 (VDD), U8.3 (VCC); also elsewhere on the board
/CAN2_H: U8.7 (CANH); also elsewhere on the board
/CAN2_L: U8.6 (CANL); also elsewhere on the board
/Microcontroller/411-IOUT: R7.2; also elsewhere on the board
/Microcontroller/MCU-UART-RX: TP3.1 (1_1), U1.1 (ISP-UART_RXD); also elsewhere on the board
/Microcontroller/MCU-UART-TX: TP13.1 (1_1), U1.2 (ISP-UART_TXD); also elsewhere on the board
/Microcontroller/NRESET: C12.1, R15.1, TP16.1 (1_1), U1.9 (RESET_B); also elsewhere on the board
/Microcontroller/P0_4: TP85.1 (1_1), U1.80 (P0_4)
/Microcontroller/P0_5: TP86.1 (1_1), U1.81 (P0_5)
/Microcontroller/P0_18: TP78.1 (1_1), U1.86 (P0_18)
/Microcontroller/P0_19: TP79.1 (1_1), U1.87 (P0_19)
/Microcontroller/P0_20: TP80.1 (1_1), U1.88 (P0_20)
/Microcontroller/P0_21: TP81.1 (1_1), U1.89 (P0_21)
/Microcontroller/P0_22: TP82.1 (1_1), U1.90 (P0_22)
/Microcontroller/P0_23: TP83.1 (1_1), U1.91 (P0_23)
/Microcontroller/P1_0: TP68.1 (1_1), U1.92 (P1_0)
/Microcontroller/P1_1: TP69.1 (1_1), U1.93 (P1_1)
/Microcontroller/P1_2: TP70.1 (1_1), U1.94 (P1_2)
/Microcontroller/P1_3: TP71.1 (1_1), U1.95 (P1_3)
/Microcontroller/P1_4: TP72.1 (1_1), U1.97 (P1_4)
/Microcontroller/P1_5: TP73.1 (1_1), U1.98 (P1_5)
/Microcontroller/P1_6: TP74.1 (1_1), U1.99 (P1_6)
/Microcontroller/P1_7: TP75.1 (1_1), U1.100 (P1_7)
/Microcontroller/P1_12: TP5.1 (1_1), U1.5 (P1_12)
/Microcontroller/P1_14: TP7.1 (1_1), U1.7 (P1_14)
/Microcontroller/P1_15: TP8.1 (1_1), U1.8 (P1_15)
/Microcontroller/P2_0: TP9.1 (1_1), U1.14 (P2_0)
/Microcontroller/P2_1: TP10.1 (1_1), U1.15 (P2_1)
/Microcontroller/P2_2: TP11.1 (1_1), U1.16 (P2_2)
/Microcontroller/P2_3: TP12.1 (1_1), U1.17 (P2_3)
/Microcontroller/P2_4: TP14.1 (1_1), U1.18 (P2_4)
/Microcontroller/P2_5: TP17.1 (1_1), U1.19 (P2_5)
/Microcontroller/P2_6: TP18.1 (1_1), U1.20 (P2_6)
/Microcontroller/P2_7: TP19.1 (1_1), U1.21 (P2_7)
/Microcontroller/P3_0: TP53.1 (1_1), U1.75 (P3_0)
/Microcontroller/P3_1: TP52.1 (1_1), U1.74 (P3_1)
/Microcontroller/P3_6: TP51.1 (1_1), U1.72 (P3_6)
/Microcontroller/P3_7: TP50.1 (1_1), U1.71 (P3_7)
/Microcontroller/P3_8: TP49.1 (1_1), U1.70 (P3_8)
/Microcontroller/P3_9: TP48.1 (1_1), U1.69 (P3_9)
/Microcontroller/P3_10: TP47.1 (1_1), U1.68 (P3_10)
/Microcontroller/P3_11: TP61.1 (1_1), U1.67 (P3_11)
/Microcontroller/P3_12: TP60.1 (1_1), U1.65 (P3_12)
/Microcontroller/P3_13: TP59.1 (1_1), U1.64 (P3_13)
/Microcontroller/P3_14: TP58.1 (1_1), U1.63 (P3_14)
/Microcontroller/P3_15: TP57.1 (1_1), U1.62 (P3_15)
/Microcontroller/P3_16: TP56.1 (1_1), U1.61 (P3_16)
/Microcontroller/P3_17: TP55.1 (1_1), U1.60 (P3_17)
/Microcontroller/P3_20: TP62.1 (1_1), U1.57 (P3_20)
/Microcontroller/P3_21: TP63.1 (1_1), U1.56 (P3_21)
/Microcontroller/P4_0: R7.1, TP30.1 (1_1), U1.22 (ADC0_A0)
/Microcontroller/P4_1: TP29.1 (1_1), U1.23 (P4_1/ANA_1)
/Microcontroller/P4_2: TP28.1 (1_1), U1.24 (P4_2)
/Microcontroller/P4_3: TP27.1 (1_1), U1.25 (P4_3)
/Microcontroller/P4_4: TP26.1 (1_1), U1.26 (ADC1_A0)
/Microcontroller/P4_5: TP25.1 (1_1), U1.27 (P4_5/ANA_5)
/Microcontroller/P4_6: TP22.1 (1_1), U1.28 (P4_6/ANA_6)
/Microcontroller/P4_7: TP20.1 (1_1), U1.29 (P4_7/ANA_7)
/Microcontroller/P4_12: TP46.1 (1_1), U1.35 (P4_12)
/Microcontroller/P4_13: TP45.1 (1_1), U1.36 (P4_13/ANA_14)
/Microcontroller/P4_15: TP44.1 (1_1), U1.37 (P4_15)
/Microcontroller/P4_16: TP43.1 (1_1), U1.38 (P4_16)
/Microcontroller/P4_17: TP42.1 (1_1), U1.39 (P4_17/ANA_18)
/Microcontroller/P4_19: TP41.1 (1_1), U1.40 (P4_19)
/Microcontroller/P4_20: TP33.1 (1_1), U1.41 (P4_20)
/Microcontroller/P4_21: TP32.1 (1_1), U1.42 (P4_21/ANA_22)
/Microcontroller/P4_23: TP54.1 (1_1), U1.43 (P4_23)
/Microcontroller/P5_0: TP64.1 (1_1), U1.48 (P5_0)
/Microcontroller/P5_1: TP65.1 (1_1), U1.49 (P5_1)
/Microcontroller/P5_2: TP66.1 (1_1), U1.50 (P5_2)
/Microcontroller/P5_3: TP67.1 (1_1), U1.51 (P5_3)
/Microcontroller/SCL: R8.1, TP77.1 (1_1), U1.85 (P0_17)
/Microcontroller/SDA: R23.1, TP76.1 (1_1), U1.84 (P0_16)
/Microcontroller/SWCLK: U1.77 (TCLK/SWCLK); also elsewhere on the board
/Microcontroller/SWDIO: U1.76 (TMS/SWDIO); also elsewhere on the board
/Microcontroller/SWO: U1.78 (TDO/SWO); also elsewhere on the board
/Microcontroller/TDI: TP84.1 (1_1), U1.79 (P0_3)
/Microcontroller/VDD_ANA: C47.1, FB1.2, U1.30 (VDD_ANA), U1.31 (VREFH)
/Microcontroller/VDD_SYS: C31.1, U1.55 (VDD_SYS)
/Microcontroller/~ISPMODE: R9.1, U1.82 (ISPMODE_N); also elsewhere on the board
GND: C6.2, C7.2, C12.2, C24.2, C25.2, C26.2, C27.2, C28.2, C29.2, C30.2, C31.2, C46.2, C47.2, C48.2, C49.2, C50.2, C51.2, C52.2, C53.2, D4.1 (K), U1.32 (VREFL), U1.33 (VSS_P4), U1.52 (VSS_DCDC), U1.101 (EP), U8.2 (GND), Y2.2 (G), Y2.4 (G); also elsewhere on the board
unnamed: D4.2 (A), R21.2
unnamed: L3.2, U1.53 (DCDC_LX)
unnamed: U1.3 (CAN0_TXD), U8.1 (TXD)
unnamed: U1.4 (CAN0_RXD), U8.4 (RXD)
unnamed: R21.1, U1.6 (P1_13)
unnamed: C25.1, U1.10 (XTAL48M), Y2.3
unnamed: C6.1, U1.11 (EXTAL48M), Y2.1
VDD_CORE: C26.1, C27.1, C29.1, L3.1, U1.12 (VDD_CORE), U1.58 (VDD_CORE)

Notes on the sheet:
Connect to CAN2 because the proto card isn't part of critical systems.
All caps are ceramic 0603 10% X5R >= 16V Vwv and AEQ unless marked
Note: Disable LDO_CORE in software for more power savings
All resistors 0603 +/- 1% and AEQ unless marked
24 MHz allows LPTMRs to work
0805
1.0 - 1.2 V depending on Active mode
VDD_BAT
"MCU"
P0/P1
ISMODE_N
CAN Transceiver

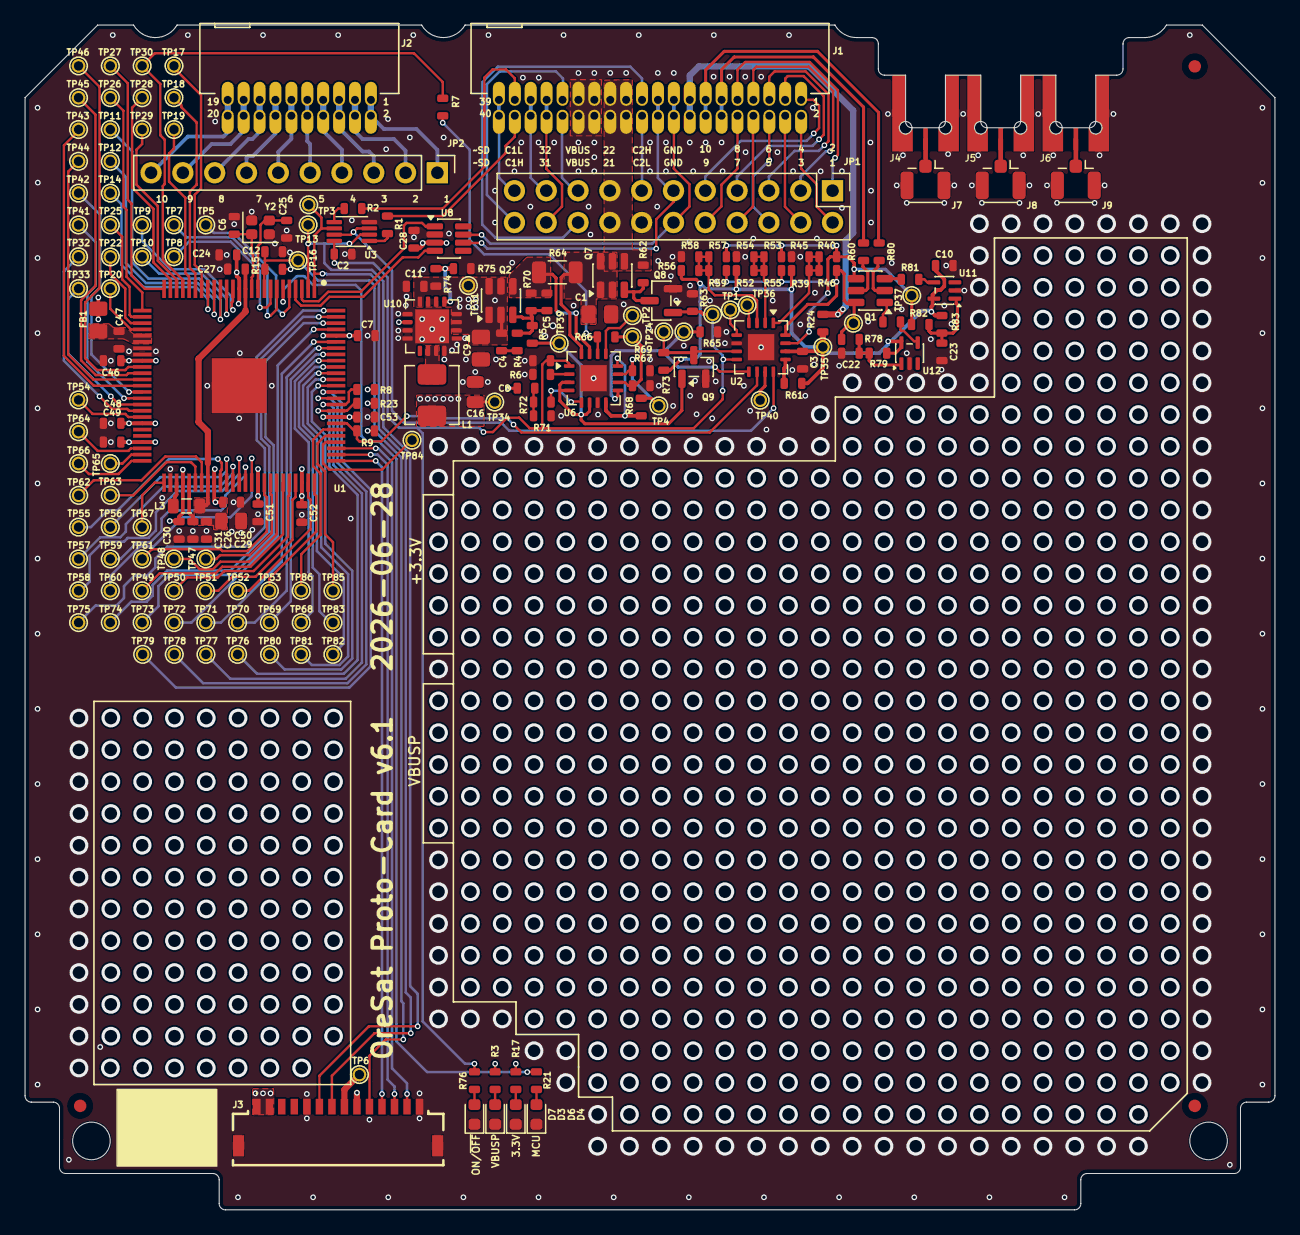
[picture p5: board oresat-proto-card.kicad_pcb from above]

Board: 4 copper layers, 99.8 x 94.6 mm, 204 parts (0 on the bottom side), 169 nets.

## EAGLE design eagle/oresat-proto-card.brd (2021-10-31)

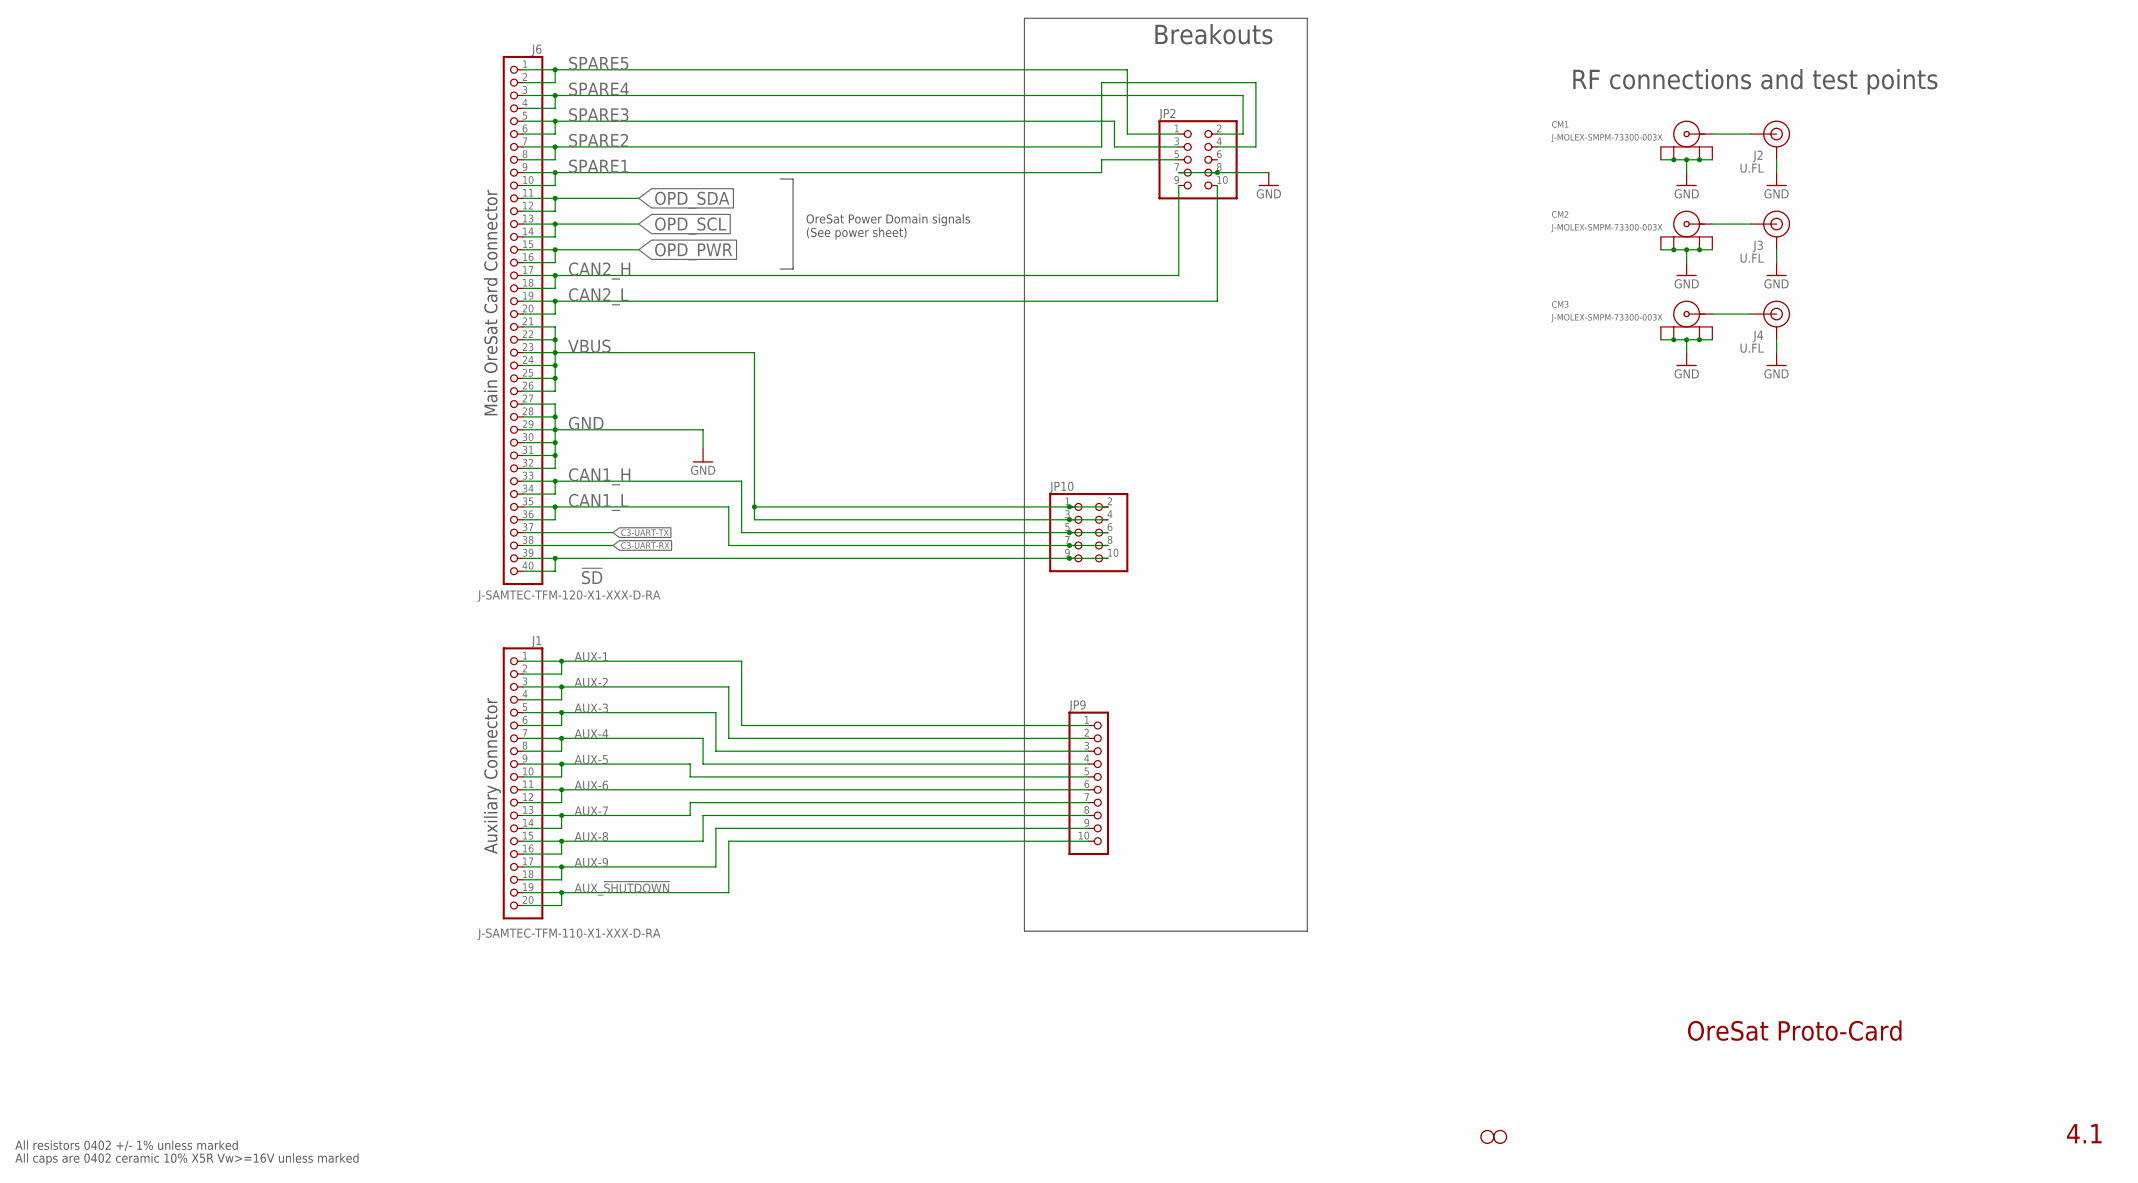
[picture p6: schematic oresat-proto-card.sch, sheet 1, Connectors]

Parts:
CM1, CM2, CM3: J-MOLEX-SMPM-73300-003X; J-MOLEX-SMPM-073300-003X; MPN 73300-0020
H2, H3: STAND-OFFTIGHT; STAND-OFF-TIGHT
J1: J-SAMTEC-TFM-110-X1-XXX-D-RA; MPN TFM-110-01-L-D-RA
J2, J3, J4: U.FL; MPN 1909763-1
J6: J-SAMTEC-TFM-120-X1-XXX-D-RA; MPN TFM-120-01-L-D-RA
JP2, JP10: PINHD-2X5; 2X05; MPN 67997-410HLF
JP9: PINHD-1X10; 1X10; MPN 61302011121

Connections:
!SD: J6.39, J6.40, JP10.9, JP10.10
AUX-1: J1.1, J1.2, JP9.1
AUX-2: J1.3, J1.4, JP9.2
AUX-3: J1.5, J1.6, JP9.3
AUX-4: J1.7, J1.8, JP9.4
AUX-5: J1.9, J1.10, JP9.5
AUX-6: J1.11, J1.12, JP9.6
AUX-7: J1.13, J1.14, JP9.7
AUX-8: J1.15, J1.16, JP9.8
AUX-9: J1.17, J1.18, JP9.9
AUX_!SHUTDOWN: J1.19, J1.20, JP9.10
C3-UART-RX: J6.38
C3-UART-TX: J6.37
CAN1_H: J6.33, J6.34, JP10.5, JP10.6
CAN1_L: J6.35, J6.36, JP10.7, JP10.8
CAN2_H: J6.17, J6.18, JP2.9; also elsewhere on the board
CAN2_L: J6.19, J6.20, JP2.10; also elsewhere on the board
GND: CM1.P$1 (SHIELD3), CM1.P$2 (SHIELD2), CM1.P$3 (SHIELD1), CM1.P$4 (SHIELD), CM2.P$1 (SHIELD3), CM2.P$2 (SHIELD2), CM2.P$3 (SHIELD1), CM2.P$4 (SHIELD), CM3.P$1 (SHIELD3), CM3.P$2 (SHIELD2), CM3.P$3 (SHIELD1), CM3.P$4 (SHIELD), J2.1 (GND), J2.2 (GND), J3.1 (GND), J3.2 (GND), J4.1 (GND), J4.2 (GND), J6.27, J6.28, J6.29, J6.30, J6.31, J6.32, JP2.7, JP2.8; also elsewhere on the board
unnamed: CM3.RF (CENTER), J4.FEED (SIGNAL)
OPD_PWR: J6.15, J6.16; also elsewhere on the board
OPD_SCL: J6.13, J6.14; also elsewhere on the board
OPD_SDA: J6.11, J6.12; also elsewhere on the board
RF1: CM1.RF (CENTER), J2.FEED (SIGNAL)
RF2: CM2.RF (CENTER), J3.FEED (SIGNAL)
SPARE1: J6.9, J6.10, JP2.5
SPARE2: J6.7, J6.8, JP2.4
SPARE3: J6.5, J6.6, JP2.3
SPARE4: J6.3, J6.4, JP2.2
SPARE5: J6.1, J6.2, JP2.1
VBUS: J6.21, J6.22, J6.23, J6.24, J6.25, J6.26, JP10.1, JP10.2, JP10.3, JP10.4; also elsewhere on the board

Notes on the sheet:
OreSat Proto-Card
4.1
All resistors 0402 +/- 1% unless marked
All caps are 0402 ceramic 10% X5R Vw>=16V unless marked
Auxiliary Connector
Main OreSat Card Connector
RF connections and test points
Breakouts
OreSat Power Domain signals (See power sheet)

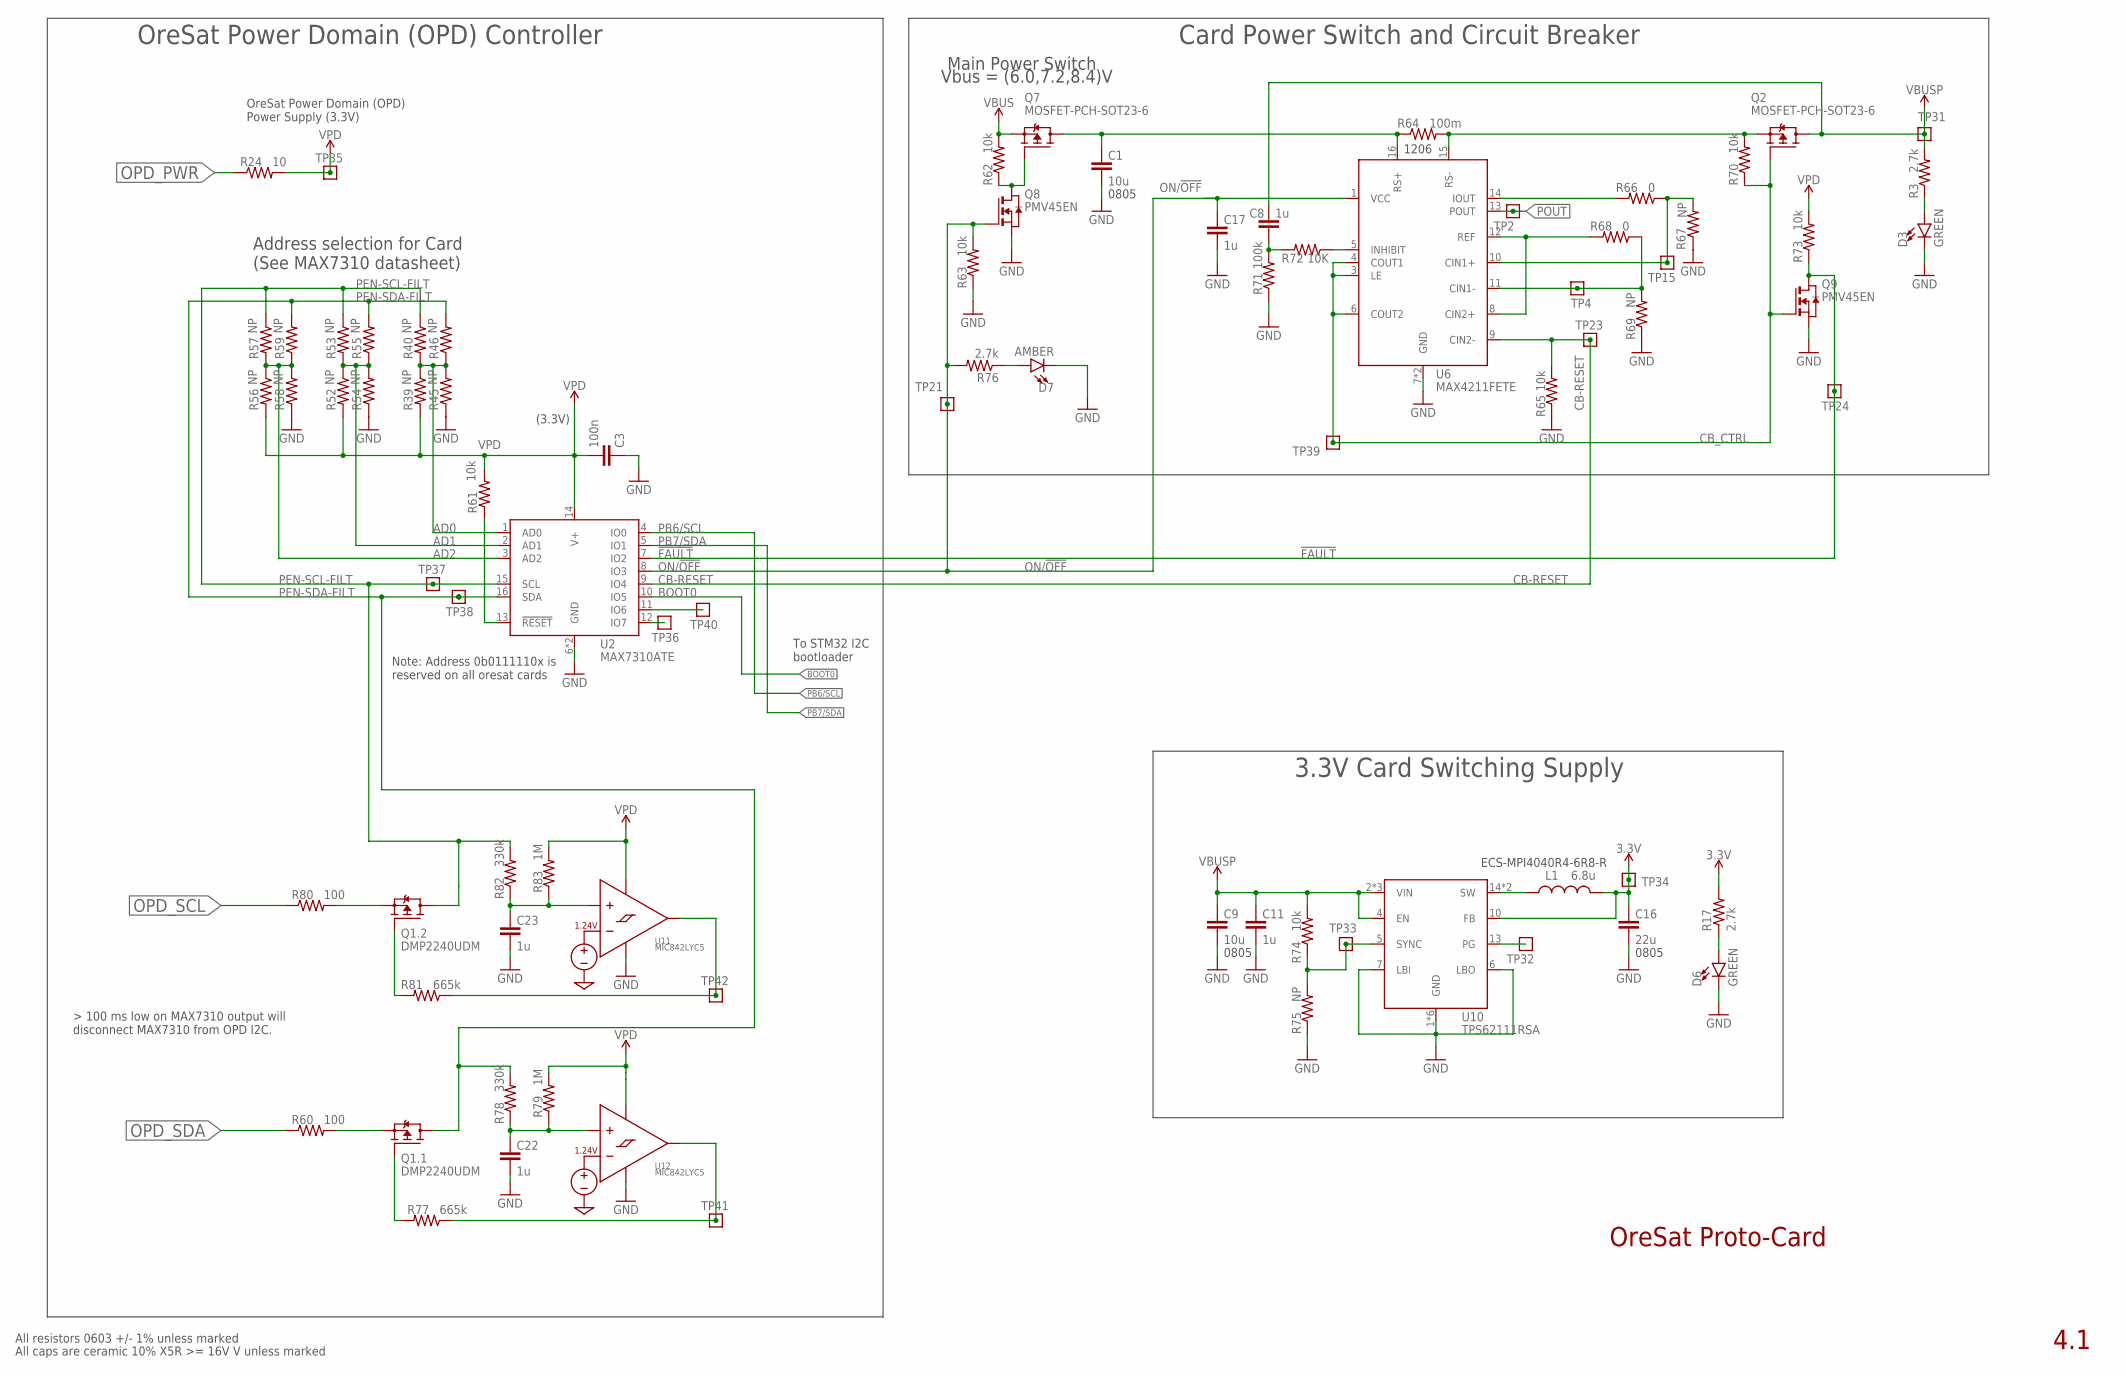
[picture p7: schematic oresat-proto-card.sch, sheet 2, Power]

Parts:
C1, C9: 10u; .0805-B-NOSILK; MPN CL21B106KOQNNNG
C3: 100n; .0603-C-NOSILK; MPN C0603C104K4PAC7867
C8: 1u; .0603-C-NOSILK
C11, C17, C22, C23: 1u; .0603-C-NOSILK; MPN CC0603KRX5R7BB105
C16: 22u; .0805-B-NOSILK; MPN GRM21BD71A226ME44L
D3, D6: GREEN; LED-0603; MPN SML-E12M8WT86
D7: AMBER; LED-0603; MPN IN-S63AT5A
L1: 6.8u; ECS-MPI4040; MPN ECS-MPI4040R4-6R8-R
Q1: DMP2240UDM; SOT23-6; MPN DMP2240UDM
Q2, Q7: MOSFET-PCH-SOT23-6; SOT23-6; MPN DMP3050LVT-7
Q8, Q9: PMV45EN; SOT23; MPN PMV45EN2R
R3, R17, R76: 2.7k; .0603-C-NOSILK; MPN ERA-3AEB272V
R24: 10; .0603-C-NOSILK; MPN RC0603FR-0710RL
R39, R40, R45, R46, R52, R53, R54, R55, R56, R57, R58, R59, R67, R69, R75: NP; .0603-C-NOSILK; MPN RC1005F6653CS
R60, R80: 100; .0603-C-NOSILK; MPN RC0603FR-07100RL
R61, R62, R63, R65, R70, R73, R74: 10k; .0603-C-NOSILK; MPN RNCP0603FTD10K0
R64: 100m; R1206; MPN CSR1206FTR100
R66, R68: 0; .0603-C-NOSILK; MPN RC0603JR-070RL
R71: 100k; .0603-C-NOSILK; MPN RC1005F6653CS
R72: 10K; .0603-C-NOSILK; MPN RC1005F6653CS
R77, R81: 665k; .0603-C-NOSILK; MPN RNCP0603FTD10K0
R78, R82: 330k; .0603-C-NOSILK; MPN CRGCQ0603F330K
R79, R83: 1M; .0603-C-NOSILK; MPN RC0603FR-071ML
TP2, TP4, TP15, TP21, TP23, TP24, TP31, TP32, TP33, TP34, TP35, TP36, TP37, TP38, TP39, TP40, TP41, TP42: TEST-POINT-LARGE-SQUARE; 1X01
U2: MAX7310ATE; QFN65P400X400X80-17T210; MPN MAX7310ATE
U6: MAX4211FETE; QFN65P400X400X80-17T210; MPN MAX4211FETE
U10: TPS62111RSA; S-PVQFN-16; MPN TPS62111RSA
U11, U12: MIC842LYC5; SC70-5

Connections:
3.3V: C16.1, L1.2, R17.2, TP34.1, U10.10 (FB); also elsewhere on the board
!FAULT: Q9.3 (D), R73.1, TP24.1, U2.7 (IO2)
AD0: R39.1, R40.2, R45.2, R46.1, U2.1 (AD0)
AD1: R52.1, R53.2, R54.2, R55.1, U2.2 (AD1)
AD2: R56.1, R57.2, R58.2, R59.1, U2.3 (AD2)
BOOT0: U2.10 (IO5); also elsewhere on the board
CB-RESET: R65.2, TP23.1, U2.9 (IO4), U6.9 (CIN2-)
CB_CTRL: Q2.3 (G), Q9.1 (G), R70.1, TP39.1, U6.3 (LE), U6.4 (COUT1), U6.6 (COUT2)
GND: C1.2, C3.1, C9.2, C11.2, C16.2, C17.2, C22.2, C23.2, D3.C, D6.C, D7.C, Q8.2 (S), Q9.2 (S), R45.1, R54.1, R58.1, R63.1, R65.1, R67.1, R69.1, R71.1, R75.1, U2.6 (GND), U2.EPAD (GND), U6.7 (GND), U6.EPAD (GND), U10.1 (GND), U10.6 (LBO), U10.7 (LBI), U10.9 (GND), U10.11 (GND), U10.12 (GND), U10.16 (GND), U10.PAD (GND), U11.2 (GND), U12.2 (GND); also elsewhere on the board
IOUT1: R66.2, U6.14 (IOUT)
unnamed: Q1.1 (G), R77.2
unnamed: Q1.3 (G), R81.2
unnamed: D3.A, R3.1
unnamed: D6.A, R17.1
unnamed: R61.1, U2.13 (!RESET)
unnamed: Q7.3 (G), Q8.3 (D), R62.1
unnamed: C1.1, Q7.1 (D), Q7.2 (D), Q7.5 (D), Q7.6 (D), R64.1, U6.16 (RS+)
unnamed: R66.1, R67.2, TP15.1, U6.10 (CIN1+)
unnamed: R68.1, R69.2, TP4.1, U6.11 (CIN1-)
unnamed: R68.2, U6.8 (CIN2+), U6.12 (REF)
unnamed: R72.1, U6.5 (INHIBIT)
unnamed: C8.1, R71.2, R72.2
unnamed: Q2.4 (S), R64.2, R70.2, U6.15 (RS-)
unnamed: D7.A, R76.1
unnamed: Q1.5 (S), R60.2
unnamed: R77.1, TP41.1, U12.4 (OUT)
unnamed: TP40.1, U2.11 (IO6)
unnamed: Q1.2 (S), R80.2
unnamed: R81.1, TP42.1, U11.4 (OUT)
unnamed: C23.1, R82.1, R83.1, U11.1 (INP)
unnamed: C22.1, R78.1, R79.1, U12.1 (INP)
unnamed: TP36.1, U2.12 (IO7)
ON/!OFF: C17.1, Q8.1 (G), R63.2, R76.2, TP21.1, U2.8 (IO3), U6.1 (VCC)
OPD_PWR: R24.1; also elsewhere on the board
OPD_SCL: R80.1; also elsewhere on the board
OPD_SDA: R60.1; also elsewhere on the board
PB6/SCL: U2.4 (IO0); also elsewhere on the board
PB7/SDA: U2.5 (IO1); also elsewhere on the board
PEN-SCL-FILT: Q1.4 (D), R40.1, R53.1, R57.1, R82.2, TP37.1, U2.15 (SCL)
PEN-SDA-FILT: Q1.6 (D), R46.2, R55.2, R59.2, R78.2, TP38.1, U2.16 (SDA)
POUT: TP2.1, U6.13 (POUT); also elsewhere on the board
TPS62111-PG1: TP32.1, U10.13 (PG)
TPS62111-SYNC1: R74.1, R75.2, TP33.1, U10.5 (SYNC)
TPS62111_SW3: L1.1, U10.14 (SW), U10.15 (SW)
VBUS: Q7.4 (S), R62.2; also elsewhere on the board
VBUSP: C8.2, C9.1, C11.1, Q2.1 (D), Q2.2 (D), Q2.5 (D), Q2.6 (D), R3.2, R74.2, TP31.1, U10.2 (VIN), U10.3 (VIN), U10.4 (EN), U10.8 (VIN); also elsewhere on the board
VPD: C3.2, R24.2, R39.2, R52.2, R56.2, R61.2, R73.2, R79.2, R83.2, TP35.1, U2.14 (V+), U11.5 (VDD), U12.5 (VDD)

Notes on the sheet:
4.1
Main Power Switch
Address selection for Card (See MAX7310 datasheet)
(3.3V)
0805
ECS-MPI4040R4-6R8-R
Vbus = (6.0,7.2,8.4)V
OreSat Power Domain (OPD) Power Supply (3.3V)
OreSat Power Domain (OPD) Controller
3.3V Card Switching Supply
Card Power Switch and Circuit Breaker
Note: Address 0b0111110x is reserved on all oresat cards
To STM32 I2C bootloader
1206
All resistors 0603 +/- 1% unless marked
All caps are ceramic 10% X5R >= 16V V unless marked
OreSat Proto-Card

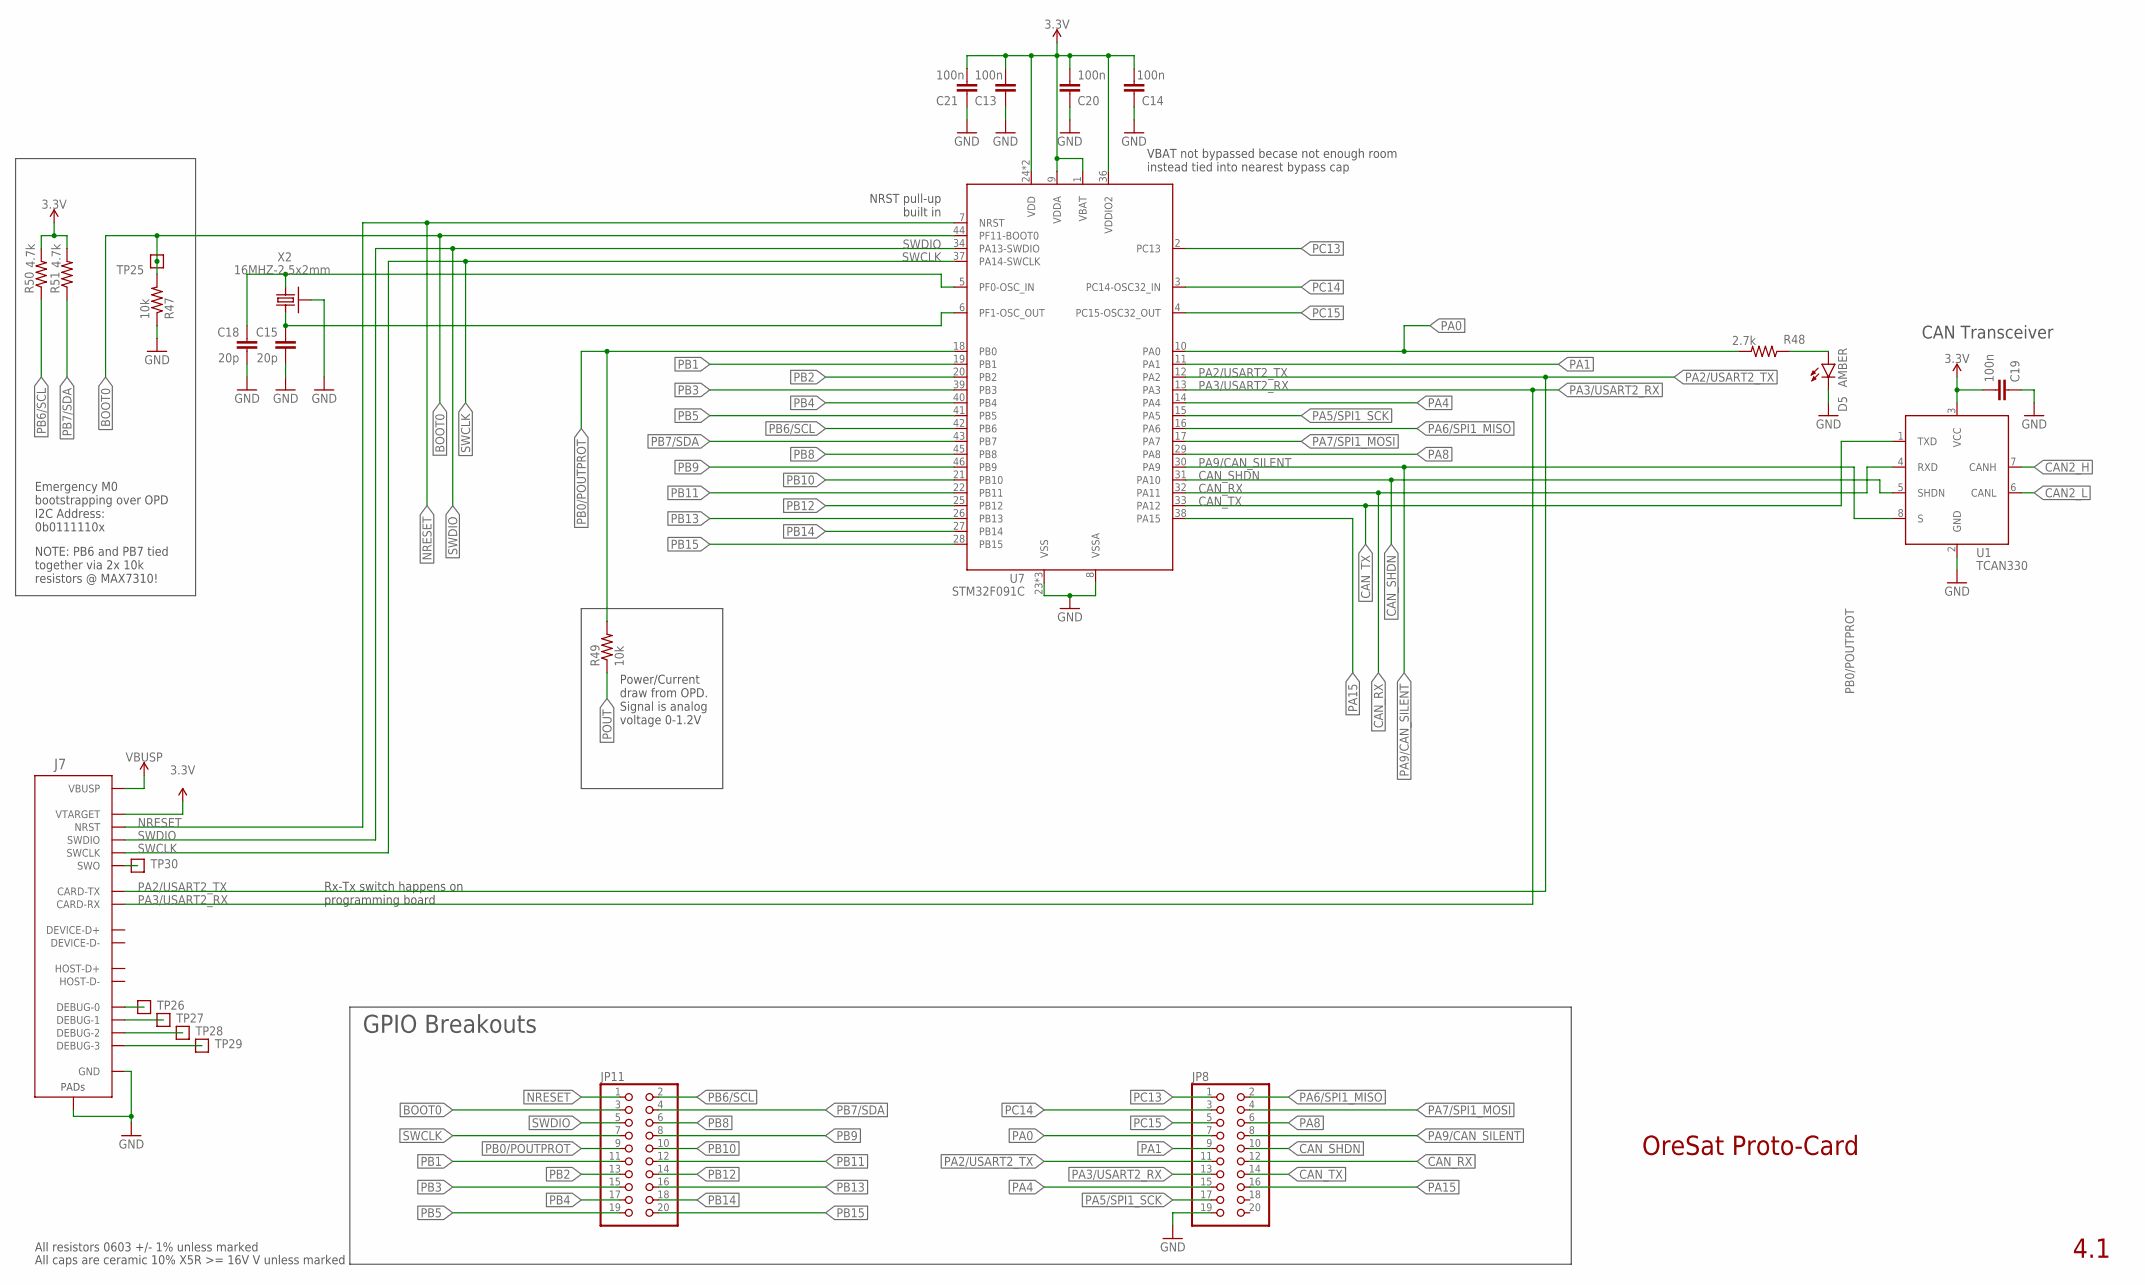
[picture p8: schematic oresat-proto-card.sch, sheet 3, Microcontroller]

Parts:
C13, C14, C19, C20, C21: 100n; .0603-C-NOSILK; MPN CL05B104KO5NNNC
C15, C18: 20p; .0603-C-NOSILK; MPN CL05C200JB51PNC
D5: AMBER; LED-0603; MPN IN-S63AT5A
J7: ORESAT-DEBUG-CONNECTOR-ALL; TE_2-1734592-0
JP8, JP11: PINHD-2X10; 2X10; MPN 67996-420HLF
R47, R49: 10k; .0603-C-NOSILK; MPN RC0402FR-0710KL
R48: 2.7k; .0603-C-NOSILK; MPN CRGCQ0402F2K7
R50, R51: 4.7k; .0603-C-NOSILK; MPN CRGCQ0402F2K7
TP25, TP26, TP27, TP28, TP29, TP30: TEST-POINT-LARGE-SQUARE; 1X01
U1: TCAN330; SOT23-8_TI-DCN; MPN TCAN330GDCNT
U7: STM32F091C; MPN STM32F042K6T7
X2: 16MHZ-2.5x2mm; CRYSTAL_2.5X2; MPN ECS-160-10-36Q-ES-TR

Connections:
3.3V: C13.2, C14.2, C19.2, C20.2, C21.2, J7.11 (VTARGET), R50.2, R51.2, U1.3 (VCC), U7.1 (VBAT), U7.9 (VDDA), U7.24 (VDD), U7.36 (VDDIO2), U7.48 (VDD); also elsewhere on the board
BOOT0: JP11.3, R47.2, TP25.1, U7.44 (PF11-BOOT0); also elsewhere on the board
CAN2_H: U1.7 (CANH); also elsewhere on the board
CAN2_L: U1.6 (CANL); also elsewhere on the board
CAN_RX: JP8.12, U1.4 (RXD), U7.32 (PA11)
CAN_SHDN: JP8.10, U1.5 (SHDN), U7.31 (PA10)
CAN_TX: JP8.14, U1.1 (TXD), U7.33 (PA12)
CRYSTALIN1: C18.1, U7.5 (PF0-OSC_IN), X2.1
CRYSTALOUT1: C15.1, U7.6 (PF1-OSC_OUT), X2.3 (2)
GND: C13.1, C14.1, C15.2, C18.2, C19.1, C20.1, C21.1, D5.C, J7.3 (GND), J7.6 (GND), J7.9 (GND), J7.PAD1 (PAD), J7.PAD2 (PAD), JP8.19, R47.1, U1.2 (GND), U7.8 (VSSA), U7.23 (VSS), U7.35 (VSS), U7.47 (VSS), X2.2 (SHIELD), X2.4 (SHIELD); also elsewhere on the board
unnamed: D5.A, R48.1
unnamed: J7.20 (DEBUG-3), TP29.1
unnamed: J7.19 (DEBUG-2), TP28.1
unnamed: J7.18 (DEBUG-1), TP27.1
unnamed: J7.17 (DEBUG-0), TP26.1
unnamed: J7.16 (SWO), TP30.1
NRESET: J7.10 (NRST), JP11.1, U7.7 (NRST)
PA0: JP8.7, R48.2, U7.10 (PA0)
PA1: JP8.9, U7.11 (PA1)
PA2/USART2_TX: J7.13 (CARD-TX), JP8.11, U7.12 (PA2)
PA3/USART2_RX: J7.12 (CARD-RX), JP8.13, U7.13 (PA3)
PA4: JP8.15, U7.14 (PA4)
PA5/SPI1_SCK: JP8.17, U7.15 (PA5)
PA6/SPI1_MISO: JP8.2, U7.16 (PA6)
PA7/SPI1_MOSI: JP8.4, U7.17 (PA7)
PA8: JP8.6, U7.29 (PA8)
PA9/CAN_SILENT: JP8.8, U1.8 (S), U7.30 (PA9)
PA15: JP8.16, U7.38 (PA15)
PB0/POUTPROT: JP11.9, R49.2, U7.18 (PB0)
PB1: JP11.11, U7.19 (PB1)
PB2: JP11.13, U7.20 (PB2)
PB3: JP11.15, U7.39 (PB3)
PB4: JP11.17, U7.40 (PB4)
PB5: JP11.19, U7.41 (PB5)
PB6/SCL: JP11.2, R50.1, U7.42 (PB6); also elsewhere on the board
PB7/SDA: JP11.4, R51.1, U7.43 (PB7); also elsewhere on the board
PB8: JP11.6, U7.45 (PB8)
PB9: JP11.8, U7.46 (PB9)
PB10: JP11.10, U7.21 (PB10)
PB11: JP11.12, U7.22 (PB11)
PB12: JP11.14, U7.25 (PB12)
PB13: JP11.16, U7.26 (PB13)
PB14: JP11.18, U7.27 (PB14)
PB15: JP11.20, U7.28 (PB15)
PC13: JP8.1, U7.2 (PC13)
PC14: JP8.3, U7.3 (PC14-OSC32_IN)
PC15: JP8.5, U7.4 (PC15-OSC32_OUT)
POUT: R49.1; also elsewhere on the board
SWCLK: J7.15 (SWCLK), JP11.7, U7.37 (PA14-SWCLK)
SWDIO: J7.14 (SWDIO), JP11.5, U7.34 (PA13-SWDIO)
VBUSP: J7.1 (VBUSP), J7.2 (VBUSP); also elsewhere on the board

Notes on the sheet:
NRST pull-up built in
CAN Transceiver
4.1
Emergency M0 bootstrapping over OPD I2C Address: 0b0111110x
NOTE: PB6 and PB7 tied together via 2x 10k resistors @ MAX7310!
Power/Current draw from OPD. Signal is analog voltage 0-1.2V
VBAT not bypassed becase not enough room instead tied into nearest bypass cap
Rx-Tx switch happens on programming board
GPIO Breakouts
All resistors 0603 +/- 1% unless marked
All caps are ceramic 10% X5R >= 16V V unless marked
OreSat Proto-Card

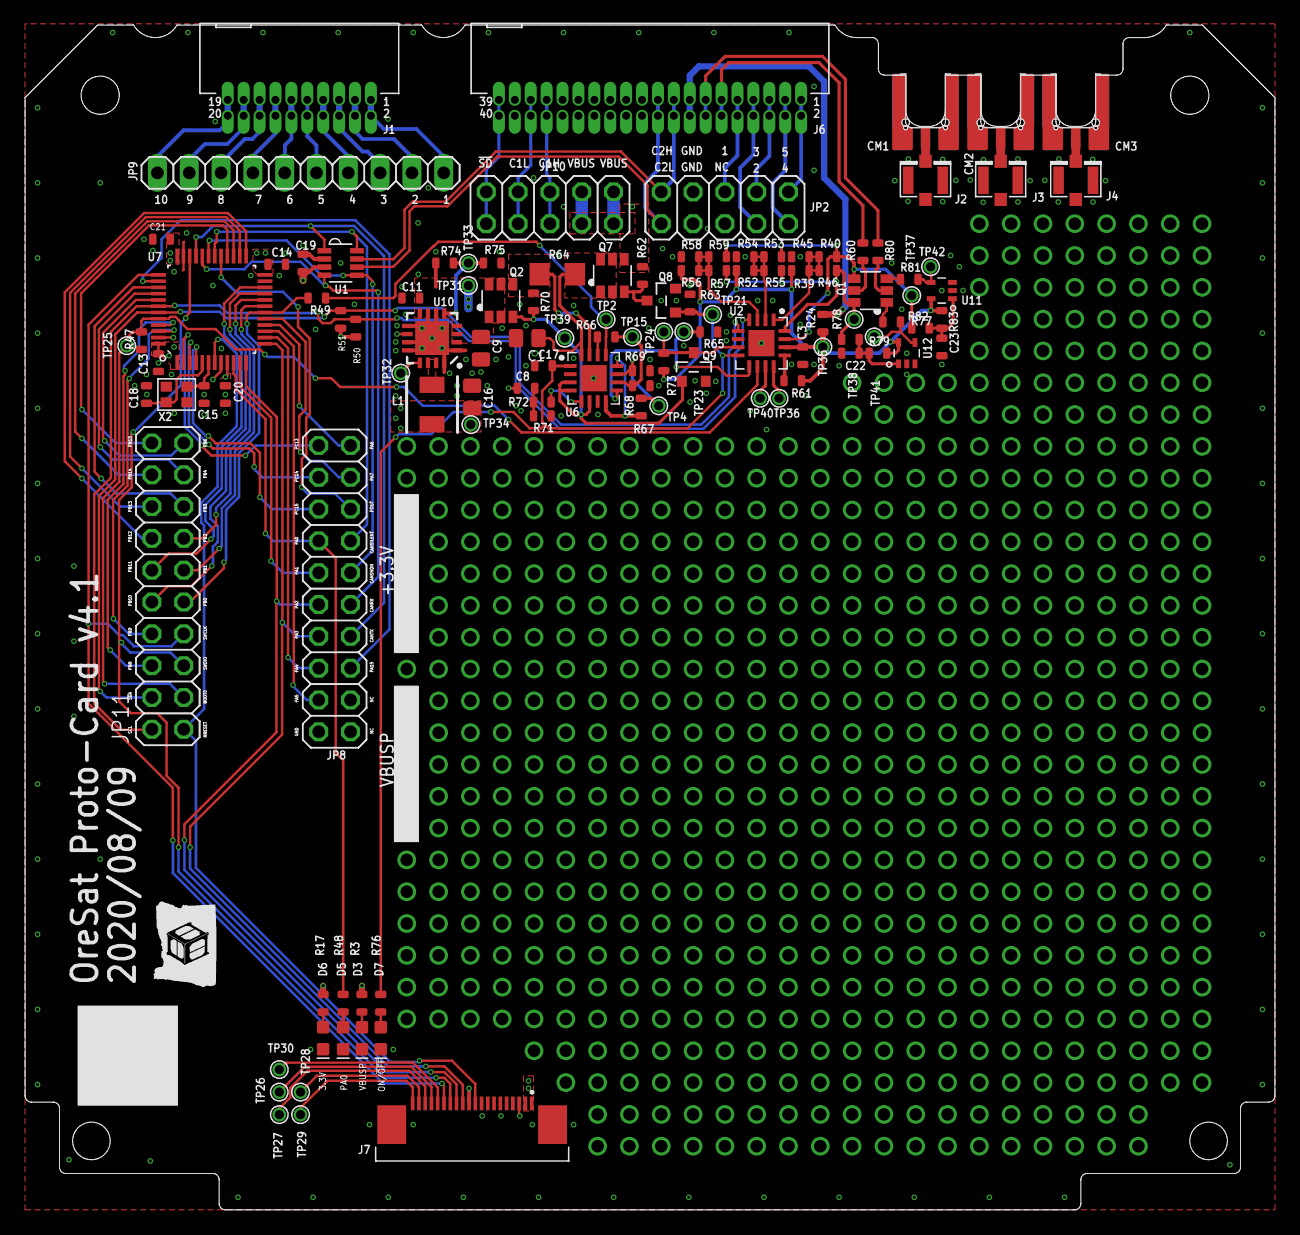
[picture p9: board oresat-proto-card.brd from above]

Board: 4 copper layers, 99.8 x 94.6 mm, 119 parts (0 on the bottom side), 112 nets.

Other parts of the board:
U$1: ORESAT-CARD-V1.3-GENERIC-3RF

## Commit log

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2017-09-22 Oh shoot I forgot text labels. K is going to hate me even more. Well, too late. Ready for v1.1!
    [oresat-proto-card.brd, oresat-proto-card.sch]
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2017-10-01 Still v1.1, but lots of changes! Moved spare lines over, added way more prototyping area, flipped around STM32 to save room, and added 3 MMCX connectors with U.FL breakouts so that we can hook up ext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
    [oresat-proto-card-7.brd, oresat-proto-card-7.sch, oresat-proto-card.brd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]
2017-10-02 Took K's suggestion: added mounting holes (not necessary in OreSat cards, but whatever) and a FTDI breakout connector. Oh, and stitched some more, and cleaned up silkscreen.
    [oresat-proto-card.brd, oresat-proto-card.sch]
2018-01-10 Updated some net names to reflect SPI bus. Actual useful BOM now.
    [oresat-proto-card.brd, oresat-proto-card.sch, oresat-proto-card.xlsx]
2018-03-06 Rough draft of the OreSat Prototype Card v2.0! Done, awaiting stapling, TNAMES checking, polish, and feedback from Miles that everything works as expected :)
    [oresat-proto-card.brd, oresat-proto-card.sch]
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2018-03-13 Now with correctly positioned main connector, 100% more auxiliary connectors, and less silly double row headers to make room for it all.
    [oresat-proto-card.brd, oresat-proto-card.sch]
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2018-03-13 Added DXF import of card outline and keepouts via DXF into the REFERENCE layer. Moved bottom connectors to get out of the way of the fingers from the +X side.
    [oresat-proto-card.brd]
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2018-03-13 Cleaned up ERC, changed VBAT to VBUS label.
    [oresat-proto-card.brd, oresat-proto-card.sch]
2018-09-11 Changes for the OreSat Backplane v1.0! Now with 100% more SMPM connectors.
    [oresat-proto-card.brd, oresat-proto-card.sch]
2018-09-11 Recovered BOM which was deleted for some reason. BOM is NOT updated! Needs work.
    [oresat-proto-card-bom.xlsx]
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2018-11-26 minor tweaks, including fixing power supply resistors.
    [oresat-proto-card.brd, oresat-proto-card.sch]
2019-02-10 Uh. Yeah. Well, it wasn't my fault, I blame Oliver J. Power domain circuitry now figured out from a topology point of view. Lots of changes to the power front end, and the main and aux connctors. Als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
    [oresat-proto-card.brd, oresat-proto-card.sch]
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2019-02-10 More schematic and board polishing. Went over ERCs and DRCs, some layout polishing, more ground stitching.
    [oresat-proto-card.brd, oresat-proto-card.sch]
2019-02-11 More board and schematic polishing. Swapped SWD connector with SMT version for easy removal. Added more test points on the MAX7210 power domain controller.
    [oresat-proto-card.brd, oresat-proto-card.sch]
2019-02-25 Latest OreSat protocard, version 3.1, with updated BOM, and design notes!
    [oresat-proto-card-bom.xlsx, oresat-proto-card.brd, oresat-proto-card.sch]
2019-02-25 Ugggh digikey made me add their part numbers. Hrmph.
    [oresat-proto-card-bom.xlsx]
2019-02-27 Added OreSat power domain -- via design blocksgit status -- and OMG it's doneish.
    [oresat-proto-card.brd, oresat-proto-card.sch]
2019-02-27 OMG next time check which repo you're in. Reverting the last commit and push.
    [oresat-proto-card.brd, oresat-proto-card.sch]
2019-03-27 Added new safety circuit on the I2C of the OPD.
    [oresat-proto-card.brd, oresat-proto-card.sch]
2019-05-22 Latest card outline from Ryan and Catie, and added the first OPD protection circuit revision.
    [oresat-proto-card.brd, oresat-proto-card.sch]
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2019-07-09 Made note of error in circuit breaker to be fixed at a later date
    [oresat-proto-card.brd, oresat-proto-card.sch]
2019-07-17 flipped comparator inputs on circuit breaker
    [oresat-proto-card.brd, oresat-proto-card.sch]
2019-07-18 updated m0 protocard to include I2C breaker CAD and added more stitching
    [oresat-proto-card.brd]
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2019-07-29 last minute drc fixes
    [oresat-proto-card.brd]
2019-07-29 fixed airwire
    [oresat-proto-card.brd]
2019-07-30 added capablity for M0 bootstrapping over OPD I2C bus. Added extra ground plane stitching. Replaced some previously removed prototyping area
    [oresat-proto-card.brd, oresat-proto-card.sch]
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2019-08-03 Final cleanup on the v3.2 protocard. Moved tall components away from the +X end of things because of the new slopes on the +X frame, and added two resistors on the OPD I2C bootloader gambit because w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
    [oresat-proto-card.brd, oresat-proto-card.sch]
2019-08-04 OMG that was close: Changes to main pinout in Backplane v2.1 did not get updated in protocard. Fixed.
    [oresat-proto-card.brd, oresat-proto-card.sch]
2019-08-04 flatsat breakout boards, one for main, one for aux, connectors.
    [flatsat-breakout-aux.brd, flatsat-breakout-aux.sch, flatsat-breakout-main.brd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]
2019-08-04 More notes after talking with David, changed I2C bootloader resistor values, and fixed AUX conector signal names.
    [oresat-proto-card.brd, oresat-proto-card.sch]
2019-08-05 Moved in +X squeezy ends by 0.15 mm on both sides.
    [oresat-proto-card.brd, oresat-proto-card.sch]
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2019-08-12 added todo on protocard to connect Iout and Pout to M0
    [oresat-proto-card-bom.xlsx, oresat-proto-card.sch]
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2019-09-28 Added new I2C protection, connected Pout to M0 through 10k
    [oresat-proto-card.sch]
2019-10-29 added board layout of new I2C protection circuit
    [oresat-proto-card.brd, oresat-proto-card.sch]
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2019-12-07 fixed j-tag connect, final tweaks for 3.3, updated bom
    [oresat-proto-card-bom.xlsx, oresat-proto-card.brd, oresat-proto-card.sch]
2019-12-17 Now v3.3. New OPD I2C protection circuits. Move to 4 layers. Lots of cleanup and massaging, but nothing worth saying. Added ground ring around 3.3V ring on L15. Attributes are still wrong, needs to b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
    [oresat-proto-card-Octavo.brd, oresat-proto-card-Octavo.sch, oresat-proto-card.brd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]
2019-12-20 fixing the lock?
    [oresat-proto-card-bom.xlsx, oresat-proto-card.brd, oresat-proto-card.sch]
2019-12-23 Fixed MIC842L flipped pins. Layout turned out to be better, too!
    [oresat-proto-card.brd, oresat-proto-card.sch]
2020-02-27 Added card debug board
    20 pin ffc edge connector debug board
    [Connector_Board.brd, Connector_Board.sch]
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2020-02-28 Clear stubs and DRC errors
    [Connector_Board.brd]
2020-02-28 clear all ERC errors
    [Connector_Board.brd, Connector_Board.sch]
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2020-02-28 Minor fixes
    Added labels
    [Connector_Board.brd]
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2020-03-03 Made changes per design review
    Added test points for RX TX rewire, made board smaller
    [Connector_Board.brd, Connector_Board.sch]
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2020-04-14 Swapped TX RX traces
    [Connector_Board.brd, Connector_Board.sch]
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2020-04-20 Version 1 of the OreSat debug board. Tinyified the board, added curved corners, centered FFC connector, added reset switch, made USB traces have a continuous ground plane, fixed FT203x VCCIO connecti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
    [Connector_Board.brd, Connector_Board.sch]
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2020-06-25 swapped 0402 to 0603 where necessary, fixed labels on tnames layer
    [oresat-proto-card.brd, oresat-proto-card.sch]
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2020-06-28 Polishing to the schematic only; ready for v4! Still needs layout polishing.
    [oresat-proto-card.brd, oresat-proto-card.sch]
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2020-06-29 moved ffc to bottom of card, fixed silkscreen, moved and expanded Vbus and 3.3V breakouts
    [oresat-proto-card.brd, oresat-proto-card.sch]
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2020-07-06 Added jumper and diode for 3.0V supply for solar for debugging without solar power.
    [Connector_Board.brd, Connector_Board.csv, Connector_Board.sch]
2020-07-06 fixed an error where Pout was not routed to an ADC pin
    [oresat-proto-card-bom.xlsx, oresat-proto-card.brd, oresat-proto-card.sch]
2020-07-20 Minor DRC clean up, fixed 3.3V plane cut by VBUSP, and some TSTOPs being too close.
    [oresat-proto-card.brd, oresat-proto-card.sch]
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2020-08-09 Added 10k resistor to the FTDI's TXD line so that we don't accidentally power the card through the transmit line)
    [Connector_Board.brd, Connector_Board.sch]
2020-08-09 Fixed RX/TX screw up (updated debug connector).
    [Connector_Board.brd, Connector_Board.sch]
2020-08-10 Updated to 4.1: switched to better debug connector, fixed OPD capacitance problem.
    [oresat-proto-card.brd, oresat-proto-card.sch]
2020-08-10 Oh right and fix the I2C pullups to 4.7k
    [oresat-proto-card.brd, oresat-proto-card.sch]
2020-12-02 Added 10 uF cap after on/off P channel switch, and added values to MAX4311 inhibit RC circuitr, all to prevent accidental trips.
    [oresat-proto-card.brd, oresat-proto-card.sch]
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2021-10-31 Fixed a handful of misc Git issues. Started KiCAD import of protocard V4.1
    [oresat-proto-card.brd, oresat-proto-card.sch]
2021-11-11 imported oresat-live-card Eagle project to KiCAD 5.99. Moved oresat-proto-card files to f0-proto-card directory
    [Connectors.kicad_sch, OSD3358_PWR,_ETC._%3a_SIP_A,_E,_F.kicad_sch, OSD3358_SD,_eMMC%3a_SIP_C,_D.kicad_sch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]
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2024-02-09 Updated proto card to new board outline and backplane pinout. Moved to KiCAD
    [Connectors.kicad_sch, Microcontroller.kicad_sch, Power.kicad_sch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]
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2024-03-22 Starting to correctly name all the protocards
    [Connectors.kicad_sch, Microcontroller.kicad_sch, OSD3358_PWR,_ETC._%3a_SIP_A,_E,_F.kicad_sch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]
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2025-06-30 Replaced J1 and JP9 w/ OreSat library equivalent
    [oresat-proto-card-sch-connectors.kicad_sch, oresat-proto-card-sch-microcontroller.kicad_sch, oresat-proto-card-sch-power.kicad_sch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]
2025-06-30 Removed and replaced eagle libraries for C, R, and Power symbols
    [oresat-proto-card-sch-connectors.kicad_sch, oresat-proto-card-sch-microcontroller.kicad_sch, oresat-proto-card-sch-power.kicad_sch]
2025-07-02 Removed and replaced Eagle libraries for MOSFET
    [oresat-proto-card-sch-connectors.kicad_sch, oresat-proto-card-sch-power.kicad_sch]
2025-07-03 Eagle libraries removed and replaced, schematic and layout clean up
    [oresat-proto-card-sch-connectors.kicad_sch, oresat-proto-card-sch-microcontroller.kicad_sch, oresat-proto-card-sch-power.kicad_sch]
2025-07-08 Eagle libraries replaced, scheatic and layout clean up cont.
    [oresat-proto-card-sch-connectors.kicad_sch, oresat-proto-card-sch-microcontroller.kicad_sch, oresat-proto-card-sch-power.kicad_sch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]
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2025-07-11 Fixed linked library footprints and routing
    [oresat-proto-card-sch-connectors.kicad_sch, oresat-proto-card-sch-microcontroller.kicad_sch, oresat-proto-card-sch-power.kicad_sch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]
2025-07-12 Fixed schematic and routing for 2x11 connector
    [oresat-proto-card-sch-connectors.kicad_sch, oresat-proto-card-sch-microcontroller.kicad_sch, oresat-proto-card-sch-power.kicad_sch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]
2025-07-14 Fixed some minor ERC and DRC errors
    [oresat-proto-card-sch-connectors.kicad_sch, oresat-proto-card.kicad_pcb]
2025-11-19 Fully routed MCXN947 proto card, still needs final polish.
    Big cleanup of the proto card's OPD, bringing it up to modern standards. Also fixed the v2 backplane connector. Added the MCXN937 processor, and breakouts for the unused pins. Switched to the new debug connector, which will be fun. That's it!
    [oresat-proto-card-sch-connectors.kicad_sch, oresat-proto-card-sch-microcontroller.kicad_sch, oresat-proto-card-sch-power.kicad_sch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]
2025-12-29 Final MCXN protocard cleanup
    Made schematic fancy with hierarchical pins, cleaned up schematics a bit, and fixed silk screen a ton. Ready for fab.
    [oresat-proto-card-sch-connectors.kicad_sch, oresat-proto-card-sch-microcontroller.kicad_sch, oresat-proto-card-sch-power.kicad_sch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]
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2025-12-30 BOM fixed; schematic polish (no change to PCB v6.0)
    Fixed BOM, and synced with OreSat BOMs Google Sheet. Figured out large capacitor (> 4.7u) voltages and package issues, which are many. Set MCXN pin names to the right selection if possible.
    [oresat-proto-card-sch-microcontroller.kicad_sch, oresat-proto-card-sch-power.kicad_sch, oresat-proto-card.kicad_pcb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]
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2026-06-28 Update protocard
    Update to 10.0.4, new .gitignore, better hierachical layout, updated footprints, re-arranged LEDs, brought outline and SMPMs into latest standards, all but OPD is updated.
    [oresat-proto-card-sch-microcontroller.kicad_sch, oresat-proto-card-sch-power.kicad_sch, oresat-proto-card.kicad_pcb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]
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2026-09-13 OPD Fix
    TCAN change from 330 to 337, added ISP TP, made PO_23:21 the version pins, added capacitor and resistor for OPD fix, and changed revision to 6.2
2026-10-19 Fixed version pins and lots of ref des formatting; BOM still not right.
2026-10-21 Fixed BOM Values
    Fixed incorrect component BOM details for C5 and C18
2026-10-21 Updated v6.2 date, fixed ERCs using power flags, fixed DRCs using custom rules and fixes. Should be good to go.
2026-11-02 Changed BOOT0/BOOT-CONFIG/ISPMODE_N to BOOT-ROM to make it generic. Added N ch MOSFET in series to both invert the BOOT-ROM signal and electrically isolate the OPD from the MCXN domain (the high sign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

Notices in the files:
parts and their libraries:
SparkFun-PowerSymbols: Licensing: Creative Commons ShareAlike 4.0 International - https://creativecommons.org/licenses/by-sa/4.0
